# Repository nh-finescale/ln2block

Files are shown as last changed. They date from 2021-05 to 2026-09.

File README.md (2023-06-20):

# ln2block

ln2block is the combination of hardware and software to send block messages in a Fremo meeting between two block enabled stations. There are more implementations for this, which can be found at [fremo-block](http://fremo-block.sourceforge.net/) The ln2block variant aims to directly connect Loconet switchpanels to block. First implementation is done with https://smf-modelle.de/ Dr-S2 panels in the Loconet variant. But other implementations such as arduino based or felderblock are possible.

## hardware

The hardware is a adaption of the boards shown [here](http://fremo-block.sourceforge.net/Loconet2Block/index.html) with the following adaptations:
- Schlüesselinterface integrated
- Arduino Nano based to ease programming and debugging
- OLED status display

v5 is a variant which has connections on both ends of the pcb.
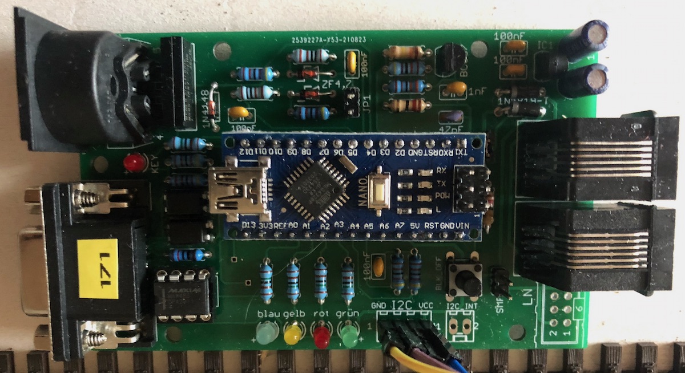
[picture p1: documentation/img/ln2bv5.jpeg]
v5 prototype


v6 is adapted to fit the Strapubox SP2000 (again).

## Getting parts:

Reichelt Shopping Cart for V5 parts: (https://www.reichelt.de/my/1871884). For logging purposes a SSD1306 OLED Display is used. Any I2C variant should work.

## Manuals:

See [the wiki](https://github.com/nh-finescale/ln2block/wiki)

## Software

Software is fully functional for:
* Tf71
* Relaisblock
* Felderblock

### Programming the Arduino

To program the Arduino please use the Arduino IDE.

#### Prerequisites:
* Wire Library (included within IDE): needed for the U8g2 Library
* U8g2 Library: to write text and/or graphic on the OLED display
* LocoNet Library: to send/receive Loconet messages

## Configuration

The ln2block software can be configured through LNCV programming. The values in scope are described at [fremo-block](http://fremo-block.sourceforge.net/Loconet2Block/config.html).
A spreadsheet to calculate the appropriate values for each LNCV is found at https://github.com/nh-finescale/ln2block/tree/main/documentation

This sheet also contains a HEX explanation to translate HEX values shown on the OLED display back into which LNCV are on and off.

## Module connectivity

todo

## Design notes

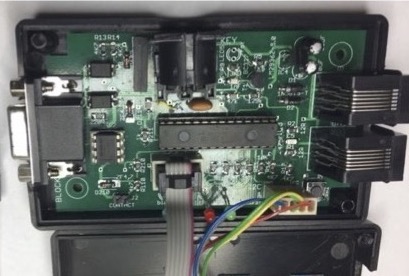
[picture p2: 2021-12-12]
documentation/img/400px/v4-400px.jpg

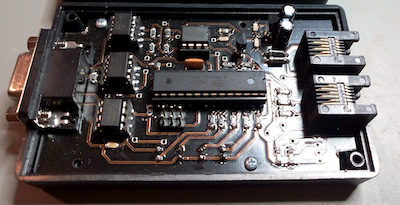
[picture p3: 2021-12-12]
documentation/img/400px/v2-400px.png

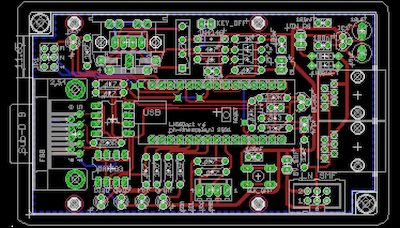
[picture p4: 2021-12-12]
documentation/img/400px/v6-400px.jpg

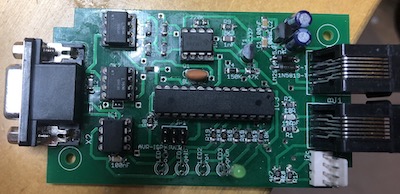
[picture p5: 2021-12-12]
documentation/img/400px/v3-400px.jpg

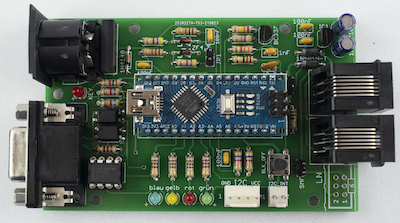
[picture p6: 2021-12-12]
documentation/img/400px/v5-400px.jpg

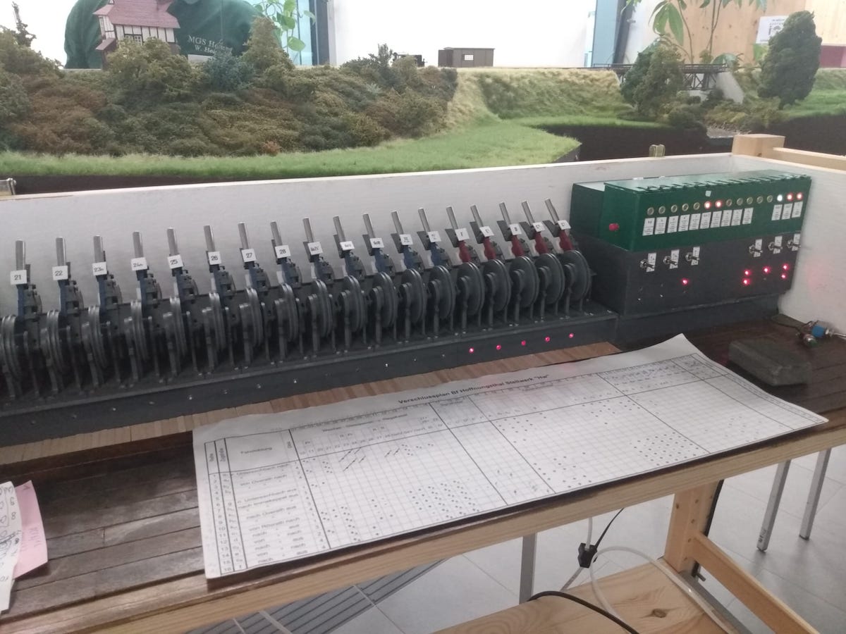
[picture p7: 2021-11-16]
documentation/img/Hoffnungstal.jpg

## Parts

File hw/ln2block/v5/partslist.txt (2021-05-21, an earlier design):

Partlist

Exported from ln2block_tht4.brd at 21/05/2021 09:19

EAGLE Version 7.6.0 Copyright (c) 1988-2016 CadSoft

Assembly variant: 

Part     Value                 Package           Library                Position (mm)         Orientation

C1       100nF                 C025-025X050      resistor               (83.5025 57.4675)     R180
C2       10uF                  E2,5-5            resistor               (95.25 55.245)        R90
C3       10uF                  E2,5-5            resistor               (95.25 61.595)        R270
C4       100nF                 C025-025X050      resistor               (83.5025 61.595)      R180
C5       100nF                 C025-025X050      resistor               (73.66 38.4175)       R90
C6       47pF                  C025-024X044      resistor               (74.6125 50.165)      R180
C7       1nF                   C025-025X050      resistor               (74.6125 53.975)      R0
C8       100nF                 C025-025X050      resistor               (56.515 59.055)       R90
C9       100nF                 C025-025X050      resistor               (35.8775 50.165)      R0
D1       1N5819-T              DO41-7.6          diode                  (86.0425 53.6575)     R0
D2                             DO41-7.6          diode                  (86.0425 50.4825)     R0
D3       1N4148                DO-1N4148         adafruit               (29.5275 54.61)       R270
D4       ZF4,7                 ZDIO-7.5          diode                  (48.5775 57.4675)     R0
D5       ZF4,7                 ZDIO-7.5          diode                  (48.5775 53.975)      R0
IC1      LM2936Z-5.0           TO92              national-semiconductor (90.17 58.42)         R270
IC2      MAX483                DIL08             maxim                  (25.4 15.5575)        R0
J1       RJ11-6L-B             RJ11-NO_SHIELD    con-tycoelectronics    (96.52 41.91)         R90
J2       I2C                   6410-04           con-molex              (73.66 10.795)        R180
J3       RJ11-6L-B             RJ11-NO_SHIELD    con-tycoelectronics    (96.52 25.4)          R90
J4       DIN                   6410-04           con-molex              (13.6525 52.07)       R270
JP1      J2                    JP1               jumper                 (56.515 52.3875)      R180
K1       Reichelt MS 7175-L 5V MEDER_MS_1A87-75L sbor                   (25.7175 60.96)       R270
LED1     gelb                  LED3MM            led                    (44.1325 10.16)       R90
LED2     rot                   LED3MM            led                    (49.8475 10.16)       R90
LED3     grün                  LED3MM            led                    (55.5625 10.16)       R90
LED4     rot                   LED3MM            led                    (61.595 10.16)        R90
LED5     blau                  LED3MM            led                    (38.735 10.16)        R90
M1       ARDUINO-NANO-3.0      ARDUINO-NANO-3.0  diy-modules            (55.88 37.1475)       R0
OK1      LTV816S               SMD4              optocoupler            (25.7175 29.21)       R270
OK2      LTV816S               SMD4              optocoupler            (25.7175 35.2425)     R270
R1       1K5                   0207/7            resistor               (44.1325 19.685)      R90
R2       1K5                   0207/7            resistor               (49.8475 19.685)      R90
R3       1K5                   0207/7            resistor               (55.5625 19.685)      R90
R4       4K7                   0207/7            resistor               (74.93 19.685)        R90
R5       4K7                   0207/7            resistor               (72.39 19.685)        R90
R6       1K5                   0207/7            resistor               (61.595 19.685)       R90
R7       12R                   0207/7            resistor               (83.82 33.655)        R90
R8       12R                   0207/7            resistor               (66.675 51.7525)      R180
R9       129k                  0207/7            resistor               (66.675 60.96)        R0
R10      3K3                   0207/7            resistor               (66.675 54.9275)      R0
R11      47k                   0207/7            resistor               (66.675 58.1025)      R180
R12      1K5                   0207/7            resistor               (39.0525 19.685)      R90
R13      220R                  0207/7            resistor               (25.0825 23.8125)     R0
R14      4K7                   0207/7            resistor               (26.035 40.005)       R0
R15      4K7                   0207/7            resistor               (26.035 42.8625)      R0
R16      4k7                   0207/7            resistor               (48.5775 50.8)        R0
R17      1k                    0207/7            resistor               (38.4175 53.975)      R0
R18      4k7                   0207/7            resistor               (38.4175 60.325)      R180
R19      1k                    0207/7            resistor               (48.5775 60.325)      R180
SW1      505-1-1-6-40-00       WS-TATV           fredi                  (87.63 12.7)          R270
T1       BC337                 TO92              transistor             (75.2475 59.3725)     R270
X1       Sub-D 9               F09HP             con-subd               (15.5575 24.4475)     R90
X2       DIN 5 180             MAB5SH            con-hirschmann         (13.335 52.07)        R270

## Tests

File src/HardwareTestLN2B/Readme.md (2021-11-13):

# HarwareTest

To test the ln2block hardware load the BlockPlatineTest software onto the Arduino Nano on the LN2B Board. In compile_options.h set the board version (supported as of now are 3,4,5 and 6).

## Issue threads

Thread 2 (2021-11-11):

Swap OLED Orientation

nh-finescale, 2021-11-11:
The OLED display is dependent on the orientation of board in the Stellwerk (if the OLED is mounted fixed on the board). To be able to read the OLED if mounted upside down, a configuration could be implemented this flips the OLED display upside down

Bahn-Papa, 2021-11-12:
Add a configuration bit 'DISPLAY_FLIP' that controls the orientation of the OLED display. If the bit is set the displayed text will be flipped (rotated by 180 degree).

Closed 2021-11-13.

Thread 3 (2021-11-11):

Handle Vorblock manually in Felderblock

nh-finescale, 2021-11-11:
A Vorblock should be handled manually in Felderblock, not automatically as in Tf71 and Relaisblock. Add a configuration switch to set Felderblock type and handle logic accordingly. Add Vorblock input Additionally?

nh-finescale, 2021-11-16:
need to test

nh-finescale, 2021-12-13:
No Vorblock possible is LNCV2 bit 4 set. Exit signal is not recognized, vorblock cannot be sent to other side

Bahn-Papa, 2022-01-05:
This bug is fixed and tested.
Felderblock is working as expected now.

Closed 2022-01-05.

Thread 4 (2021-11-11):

Reset 1ste Achse counter to simulate Letzte Achse

nh-finescale, 2021-11-11:
Reset timer for Letzte Achse after each Track Occupied message so that complete train is able to be detected before Rueckblock can be done

Closed 2021-11-15.

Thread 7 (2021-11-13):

block_on_off not working?

nh-finescale, 2021-11-13:
pressing block_on_of button does not result in clear shutdown of block

Bahn-Papa, 2022-01-05:
This feature is implemented now.
A short press to the button will toggle between Block ON and OFF.
The state will be shown on the display.

Closed 2022-01-05.

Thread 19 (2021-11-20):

Need to send EINFAHR_KONTAKT again to leave state 1._ACHSE

Kleinbahner, 2021-11-20:
When receiving a train, the message EINFAHR_KONTAKT has to be send in order to change the state to 1._ACHSE. Then a second message EINFAHR_KONTAKT has to be send in order to go to state GERAEUMT. This might be difficult when using a current sensor that is longer then the loco. There, only one message will be generated.
Could this be changed to automatically forward to the next state or to react on a inverted EINFAHR_KONTAKT message (contact released)?

nh-finescale, 2021-11-30:
issue is related to new config bits for 3 timers, which is separate issue. This one can be closed

Closed 2021-11-30.

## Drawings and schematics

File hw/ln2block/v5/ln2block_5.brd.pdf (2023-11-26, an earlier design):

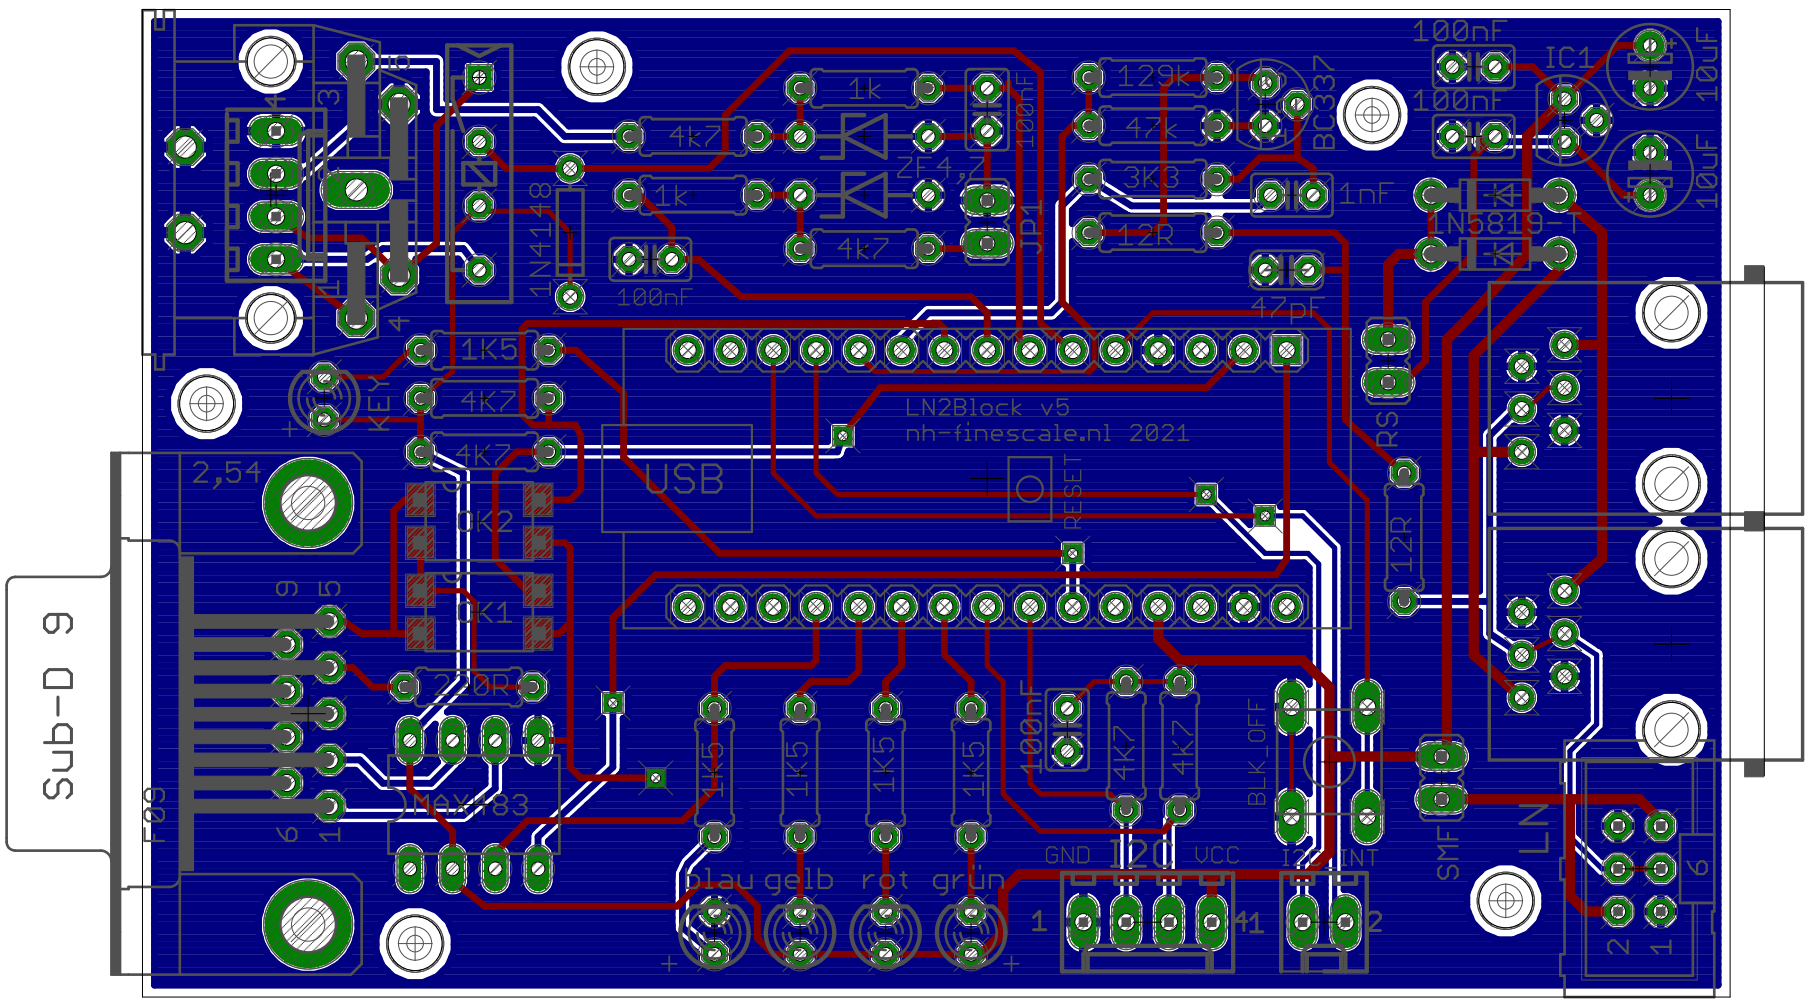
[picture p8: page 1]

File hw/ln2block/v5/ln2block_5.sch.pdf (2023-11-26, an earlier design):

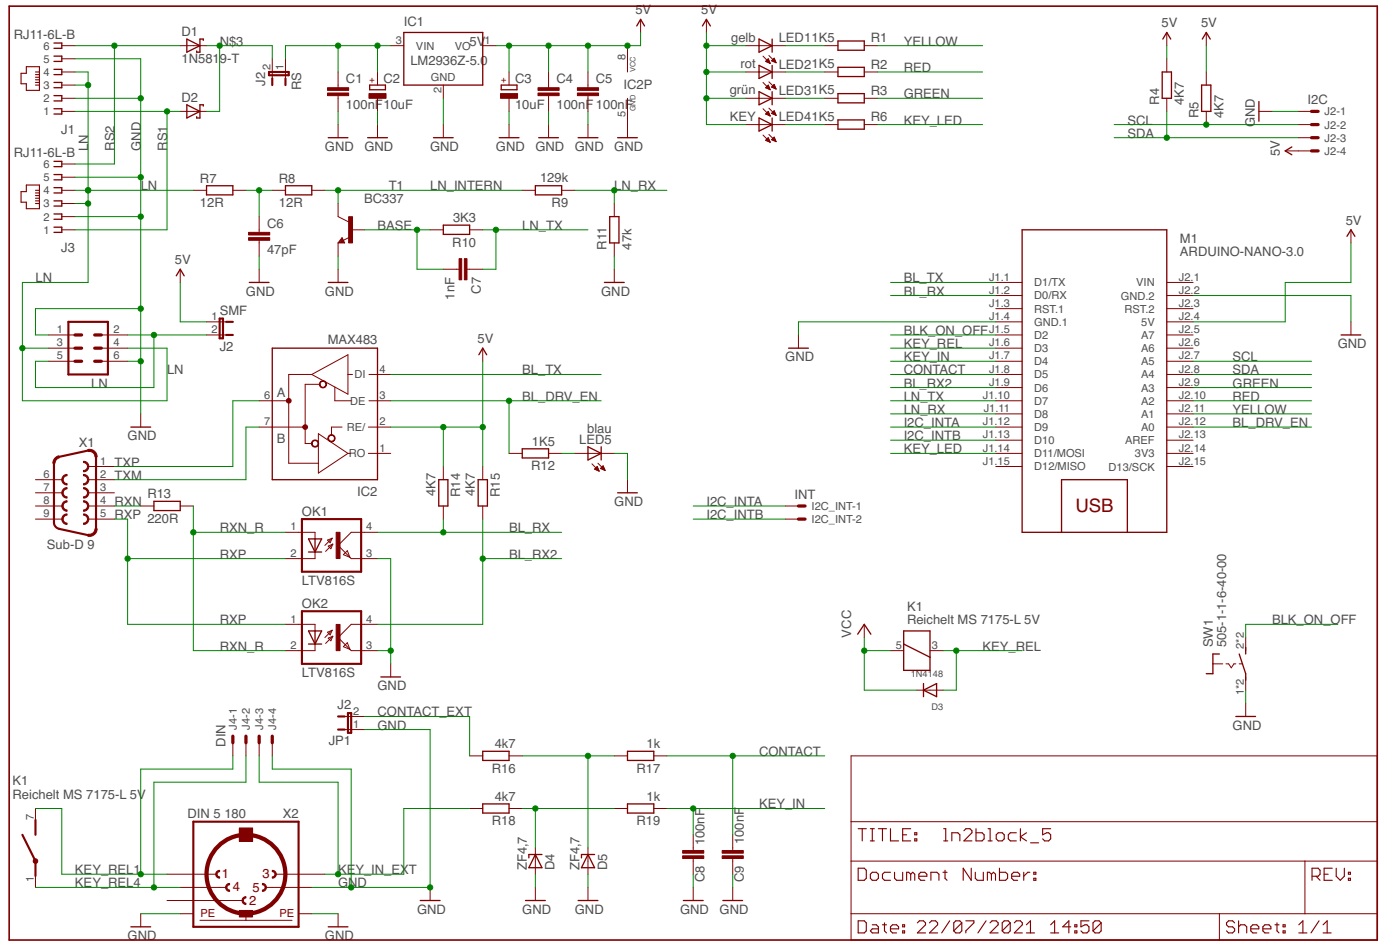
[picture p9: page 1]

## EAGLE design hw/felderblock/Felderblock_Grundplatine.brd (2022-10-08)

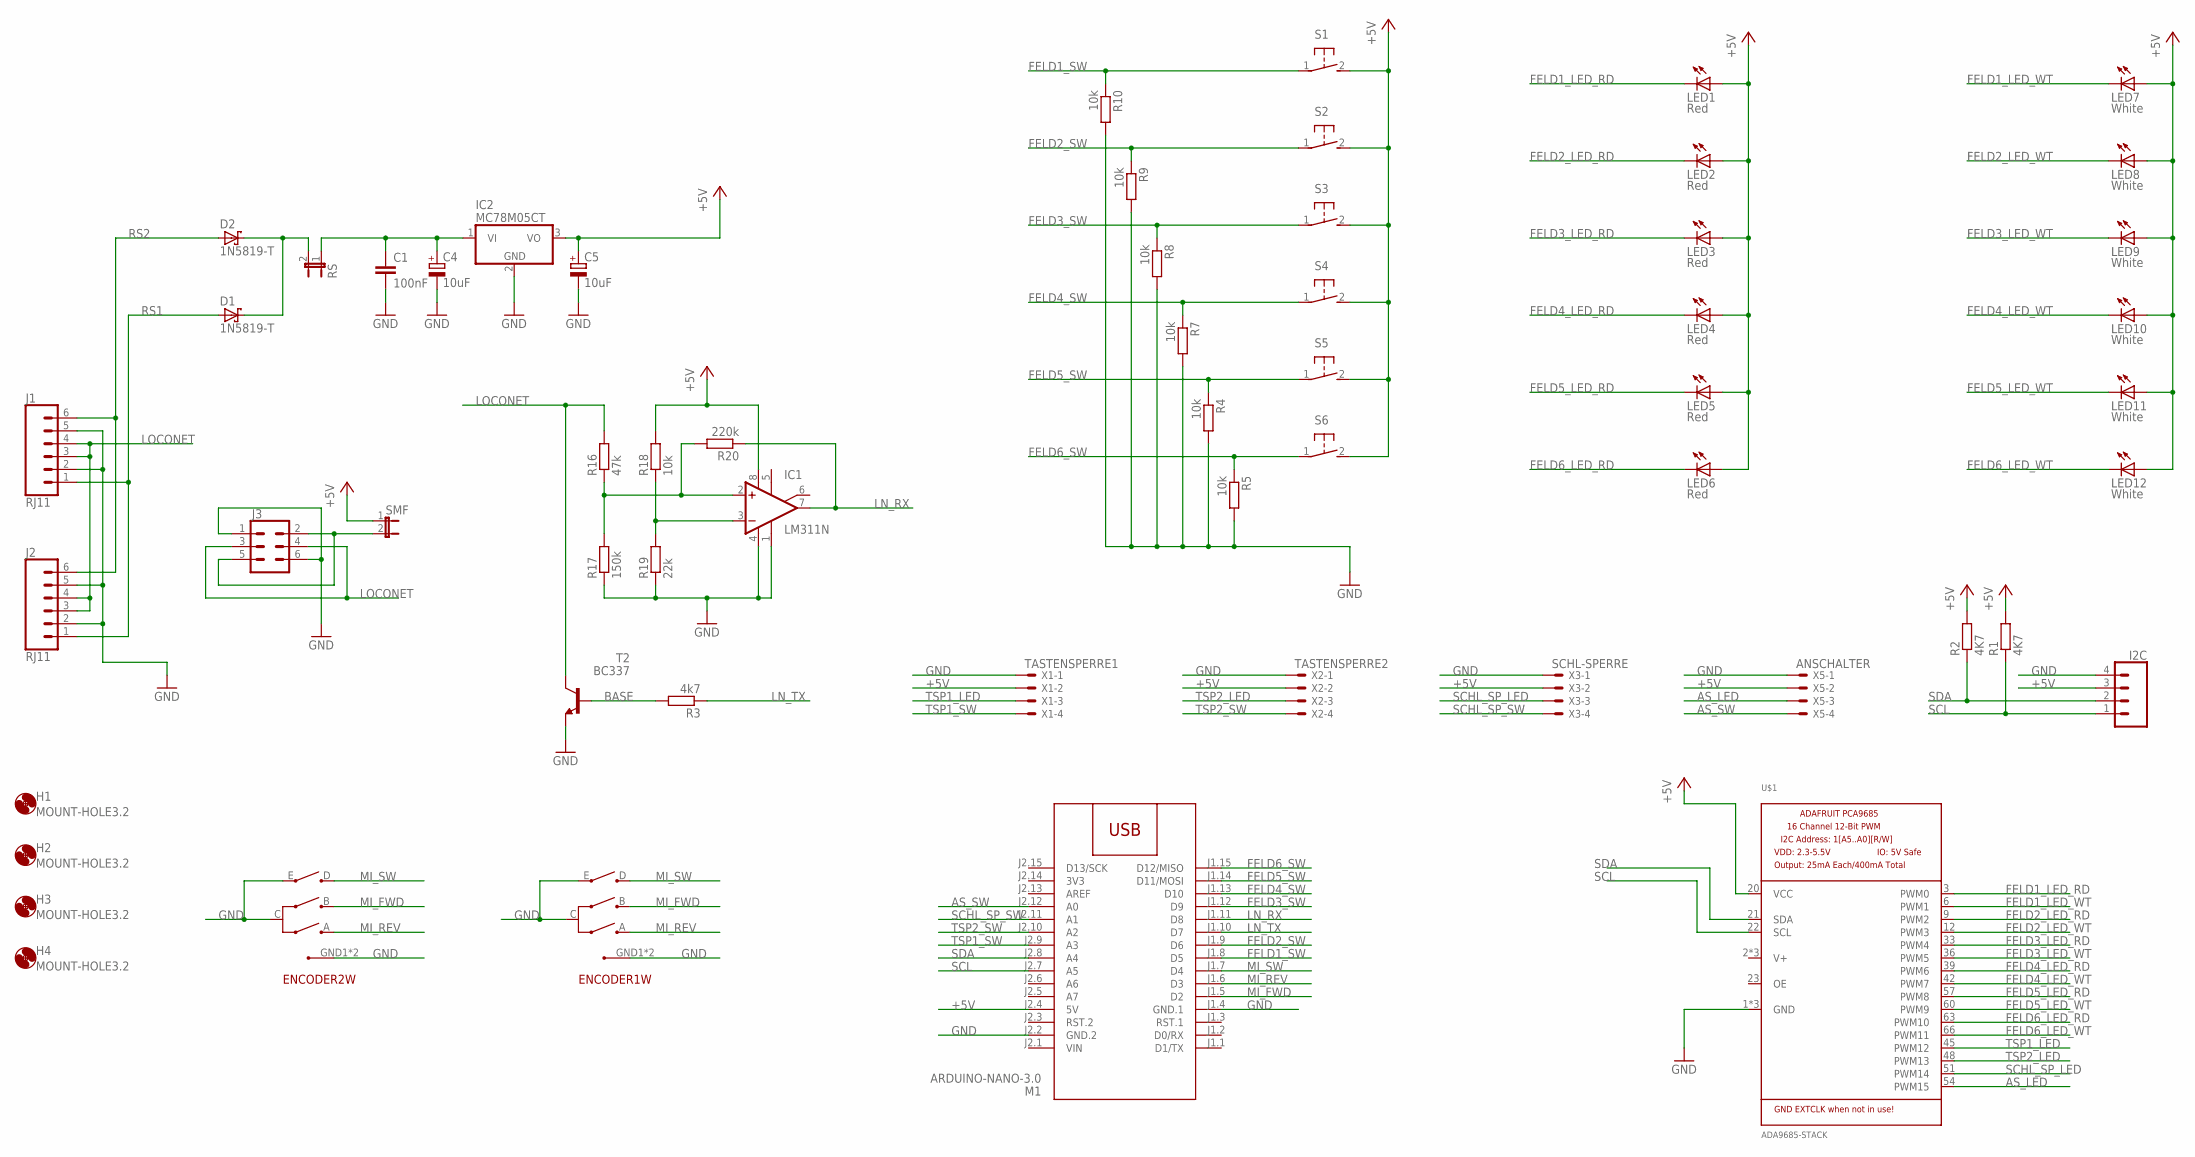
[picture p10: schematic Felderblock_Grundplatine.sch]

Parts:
C1: 100nF; C025-025X050
C4, C5: 10uF; E2-5
D1, D2: 1N5819-T; DO41-7.6
ENCODER1, ENCODER2: EC11B42AE; EC11B42
H1, H2, H3, H4: MOUNT-HOLE3.2; 3,2
I2C: CONN_04JST-PTH-VERT; JST-4-PTH-VERT
IC1: LM311N; DIL08
IC2: MC78M05CT; TO220V
J1, J2: RJ11; RJ11-6
J3: CONN_03X2SHROUD; 2X3-SHROUDED
LED1, LED2, LED3, LED4, LED5, LED6: Red; LED3MM
LED7, LED8, LED9, LED10, LED11, LED12: White; LED3MM
M1: ARDUINO-NANO-3.0
R1, R2: 4K7; 0207/7
R3: 4k7; 0207/7
R4, R5, R7, R8, R9, R10, R18: 10k; 0207/7
R16: 47k; 0207/7
R17: 150k; 0207/7
R19: 22k; 0207/7
R20: 220k; 0207/7
RS: JP1E; JP1
S1, S2, S3, S4, S5, S6: 31-XX; B3F-31XX
SMF: JP1E; JP1
T2: BC337; TO92
U$1: ADA9685-STACK
X1: TASTENSPERRE1; 22-23-2041
X2: TASTENSPERRE2; 22-23-2041
X3: SCHL-SPERRE; 22-23-2041
X5: ANSCHALTER; 22-23-2041

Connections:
3V3: M1.J2.14 (3V3)
+5V: C5.+, I2C.3, IC1.8 (V+), IC2.3 (VO), LED1.A, LED2.A, LED3.A, LED4.A, LED5.A, LED6.A, LED7.A, LED8.A, LED9.A, LED10.A, LED11.A, LED12.A, M1.J2.4 (5V), R1.2, R2.2, R18.2, S1.2 (S), S2.2 (S), S3.2 (S), S4.2 (S), S5.2 (S), S6.2 (S), SMF.1, U$1.20 (VCC), X1.2, X2.2, X3.2, X5.2
AS_LED: U$1.54 (PWM15), X5.3
AS_SW: M1.J2.12 (A0), X5.4
BASE: R3.2, T2.2 (B)
FELD1_LED_RD: LED1.K (C), U$1.3 (PWM0)
FELD1_LED_WT: LED7.K (C), U$1.6 (PWM1)
FELD1_SW: M1.J1.8 (D5), R10.1, S1.1
FELD2_LED_RD: LED2.K (C), U$1.9 (PWM2)
FELD2_LED_WT: LED8.K (C), U$1.12 (PWM3)
FELD2_SW: M1.J1.9 (D6), R9.1, S2.1
FELD3_LED_RD: LED3.K (C), U$1.33 (PWM4)
FELD3_LED_WT: LED9.K (C), U$1.36 (PWM5)
FELD3_SW: M1.J1.12 (D9), R8.1, S3.1
FELD4_LED_RD: LED4.K (C), U$1.39 (PWM6)
FELD4_LED_WT: LED10.K (C), U$1.42 (PWM7)
FELD4_SW: M1.J1.13 (D10), R7.1, S4.1
FELD5_LED_RD: LED5.K (C), U$1.57 (PWM8)
FELD5_LED_WT: LED11.K (C), U$1.60 (PWM9)
FELD5_SW: M1.J1.14 (D11/MOSI), R4.1, S5.1
FELD6_LED_RD: LED6.K (C), U$1.63 (PWM10)
FELD6_LED_WT: LED12.K (C), U$1.66 (PWM11)
FELD6_SW: M1.J1.15 (D12/MISO), R5.1, S6.1
GND: C1.2, C4.-, C5.-, ENCODER1.C, ENCODER1.E, ENCODER1.GND1 (GND), ENCODER1.GND2 (GND), ENCODER2.C, ENCODER2.E, ENCODER2.GND1 (GND), ENCODER2.GND2 (GND), I2C.4, IC1.1 (GND), IC1.4 (V-), IC2.2 (GND), J1.2, J1.5, J2.2, J2.5, J3.1, J3.6, M1.J1.4 (GND.1), M1.J2.2 (GND.2), R4.2, R5.2, R7.2, R8.2, R9.2, R10.2, R17.1, R19.1, T2.1 (E), U$1.1 (GND), U$1.24 (GND), U$1.52 (GND), X1.1, X2.1, X3.1, X5.1
LN_RX: IC1.7 (OUT), M1.J1.11 (D8), R20.1
LN_TX: M1.J1.10 (D7), R3.1
LOCONET: J1.3, J1.4, J2.3, J2.4, J3.3, J3.4, R16.2, T2.3 (C)
MI_FWD: ENCODER1.B, ENCODER2.B, M1.J1.5 (D2)
MI_REV: ENCODER1.A, ENCODER2.A, M1.J1.6 (D3)
MI_SW: ENCODER1.D, ENCODER2.D, M1.J1.7 (D4)
unnamed: IC1.2 (+IN), R16.1, R17.2, R20.2
unnamed: D1.C, D2.C, RS.2
unnamed: C1.1, C4.+, IC2.1 (VI), RS.1
unnamed: IC1.3 (-IN), R18.1, R19.2
unnamed: J3.2, J3.5, SMF.2
RS1: D1.A, J1.1, J2.1
RS2: D2.A, J1.6, J2.6
SCHL_SP_LED: U$1.51 (PWM14), X3.3
SCHL_SP_SW: M1.J2.11 (A1), X3.4
SCL: I2C.1, M1.J2.7 (A5), R1.1, U$1.22 (SCL)
SDA: I2C.2, M1.J2.8 (A4), R2.1, U$1.21 (SDA)
TSP1_LED: U$1.45 (PWM12), X1.3
TSP1_SW: M1.J2.9 (A3), X1.4
TSP2_LED: U$1.48 (PWM13), X2.3
TSP2_SW: M1.J2.10 (A2), X2.4
VIN: M1.J2.1 (VIN)

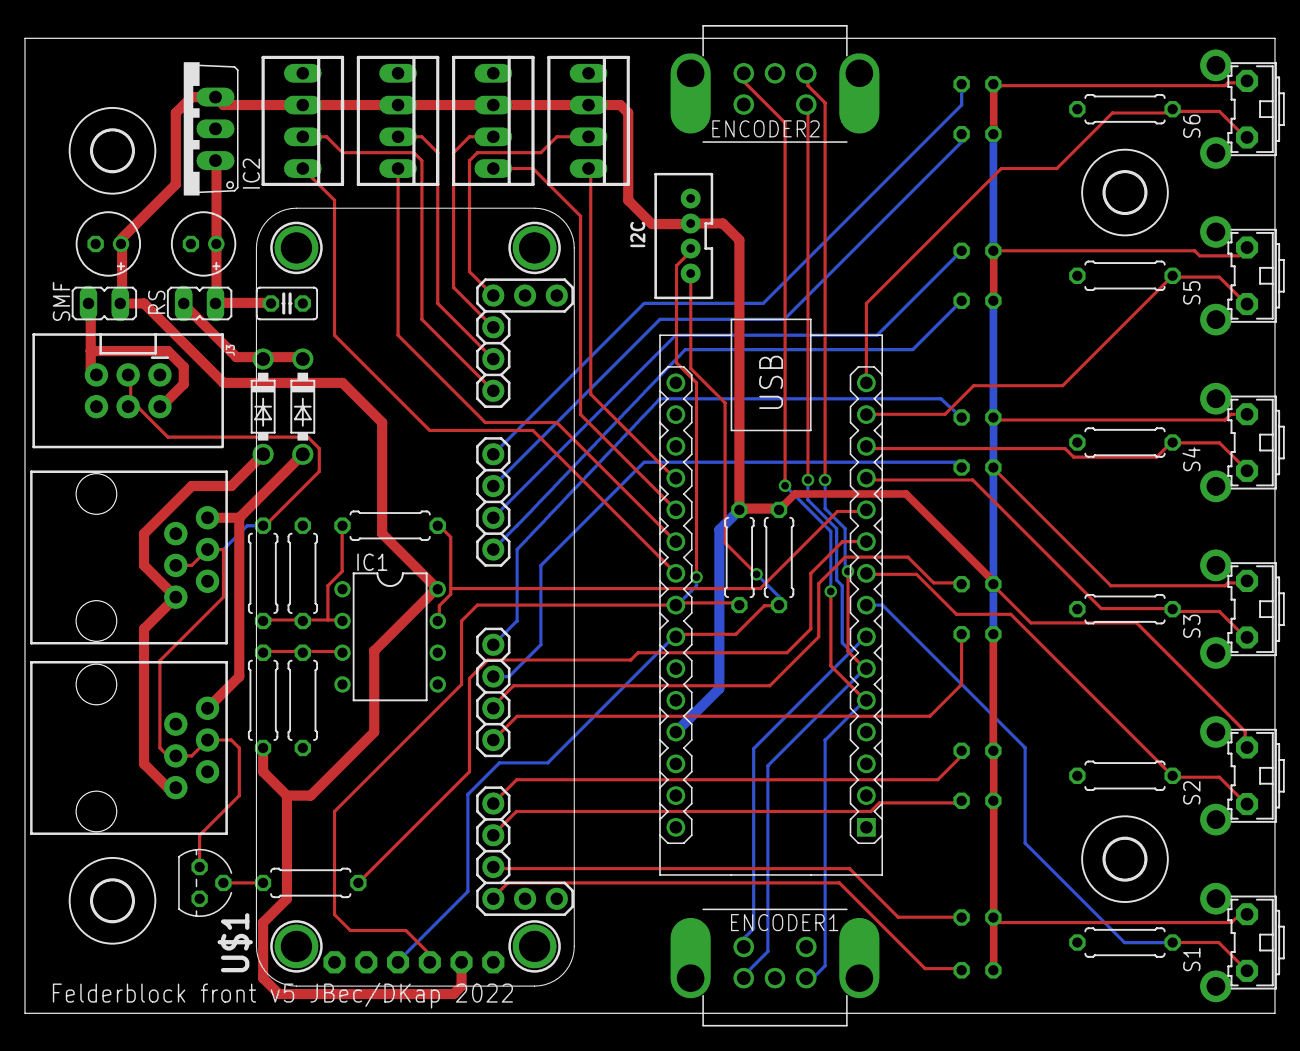
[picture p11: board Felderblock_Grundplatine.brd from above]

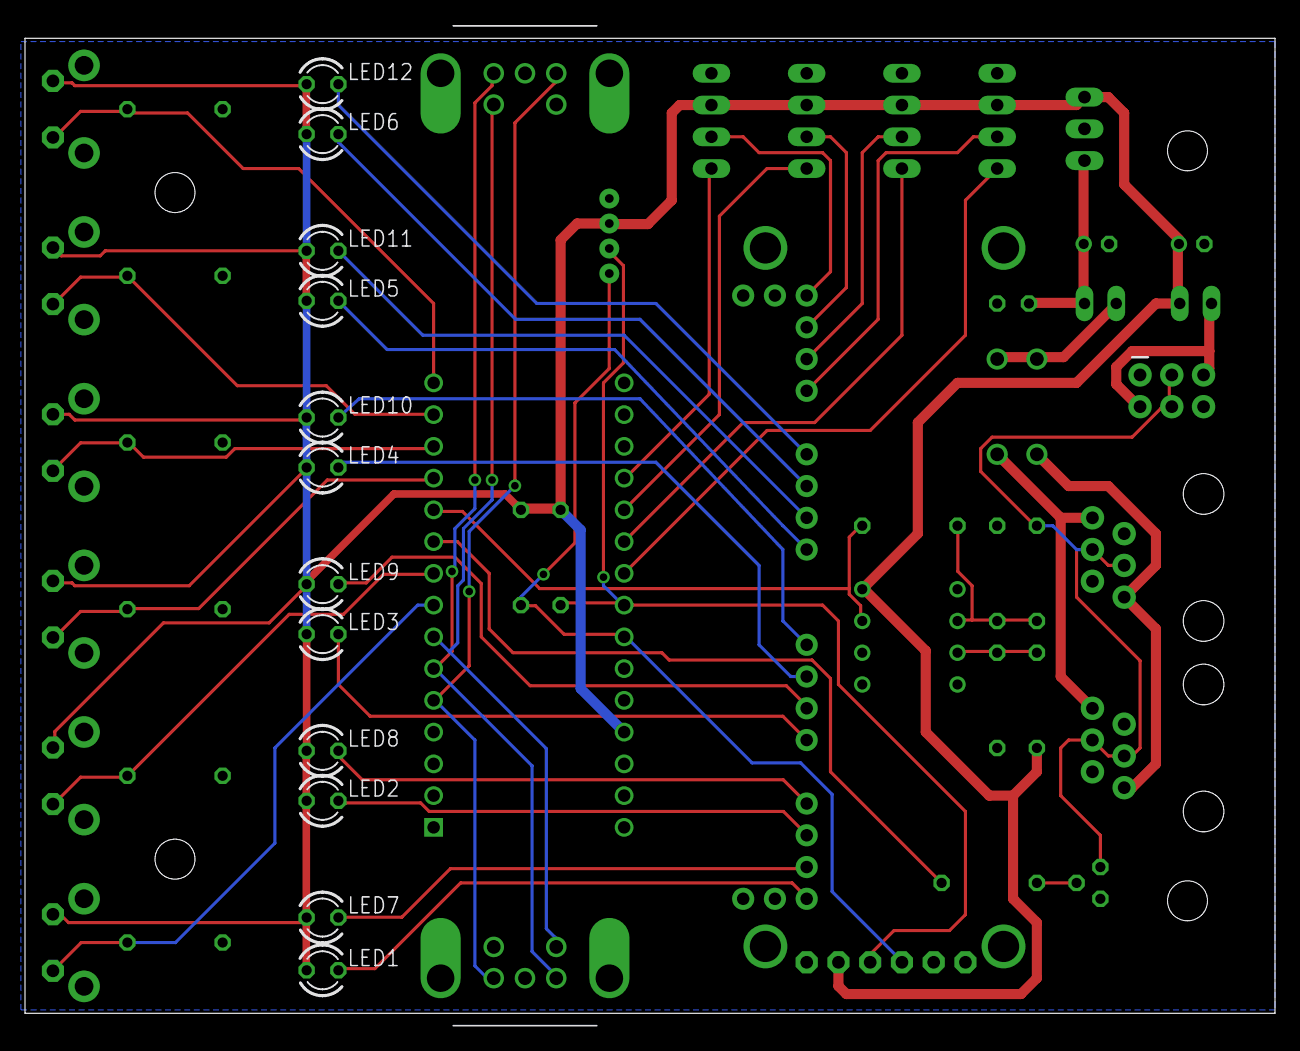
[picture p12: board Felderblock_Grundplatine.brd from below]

Board: 2 copper layers, 100.0 x 80.0 mm, 58 parts (12 on the bottom side), 44 nets.

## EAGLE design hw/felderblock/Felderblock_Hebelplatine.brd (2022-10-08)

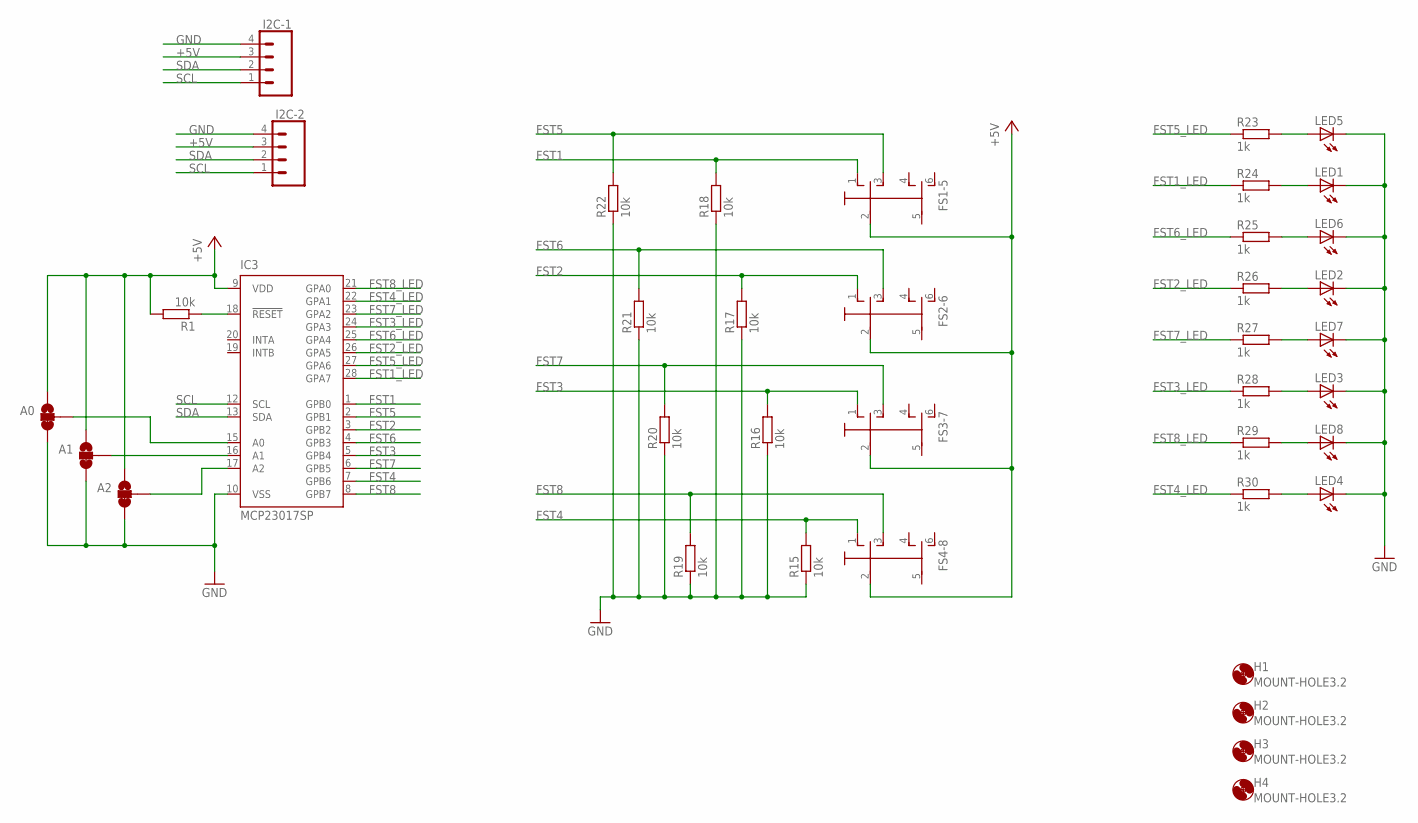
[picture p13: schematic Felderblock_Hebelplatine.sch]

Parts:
A0, A1, A2: JUMPER-SMT_3_1-NC_TRACE_SILK; SMT-JUMPER_3_1-NC_TRACE_SILK
FS1-5, FS2-6, FS3-7, FS4-8: SW_2POL_ON-OFF-ONSOLDERPAD; DIL6_LARGE
H1, H2, H3, H4: MOUNT-HOLE3.2; 3,2
I2C-1, I2C-2: CONN_04JST-PTH-VERT; JST-4-PTH-VERT
IC3: MCP23017SP; DIL28-3
LED1, LED2, LED3, LED4, LED5, LED6, LED7, LED8: LED3MM
R1, R15, R16, R17, R18, R19, R20, R21, R22: 10k; 0207/7
R23, R24, R25, R26, R27, R28, R29, R30: 1k; 0207/7

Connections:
+5V: A0.1, A1.1, A2.1, FS1-5.2, FS2-6.2, FS3-7.2, FS4-8.2, I2C-1.3, I2C-2.3, IC3.9 (VDD), R1.2
FST1: FS1-5.1 (O), IC3.1 (GPB0), R18.2
FST1_LED: IC3.28 (GPA7), R24.1
FST2: FS2-6.1 (O), IC3.3 (GPB2), R17.2
FST2_LED: IC3.26 (GPA5), R26.1
FST3: FS3-7.1 (O), IC3.5 (GPB4), R16.2
FST3_LED: IC3.24 (GPA3), R28.1
FST4: FS4-8.1 (O), IC3.7 (GPB6), R15.2
FST4_LED: IC3.22 (GPA1), R30.1
FST5: FS1-5.3 (S), IC3.2 (GPB1), R22.2
FST5_LED: IC3.27 (GPA6), R23.1
FST6: FS2-6.3 (S), IC3.4 (GPB3), R21.2
FST6_LED: IC3.25 (GPA4), R25.1
FST7: FS3-7.3 (S), IC3.6 (GPB5), R20.2
FST7_LED: IC3.23 (GPA2), R27.1
FST8: FS4-8.3 (S), IC3.8 (GPB7), R19.2
FST8_LED: IC3.21 (GPA0), R29.1
GND: A0.3, A1.3, A2.3, I2C-1.4, I2C-2.4, IC3.10 (VSS), LED1.K (C), LED2.K (C), LED3.K (C), LED4.K (C), LED5.K (C), LED6.K (C), LED7.K (C), LED8.K (C), R15.1, R16.1, R17.1, R18.1, R19.1, R20.1, R21.1, R22.1
unnamed: A0.2, IC3.15 (A0)
unnamed: A2.2, IC3.17 (A2)
unnamed: A1.2, IC3.16 (A1)
unnamed: IC3.18 (!RESET), R1.1
unnamed: LED5.A, R23.2
unnamed: LED1.A, R24.2
unnamed: LED6.A, R25.2
unnamed: LED2.A, R26.2
unnamed: LED7.A, R27.2
unnamed: LED3.A, R28.2
unnamed: LED8.A, R29.2
unnamed: LED4.A, R30.2
SCL: I2C-1.1, I2C-2.1, IC3.12 (SCL)
SDA: I2C-1.2, I2C-2.2, IC3.13 (SDA)

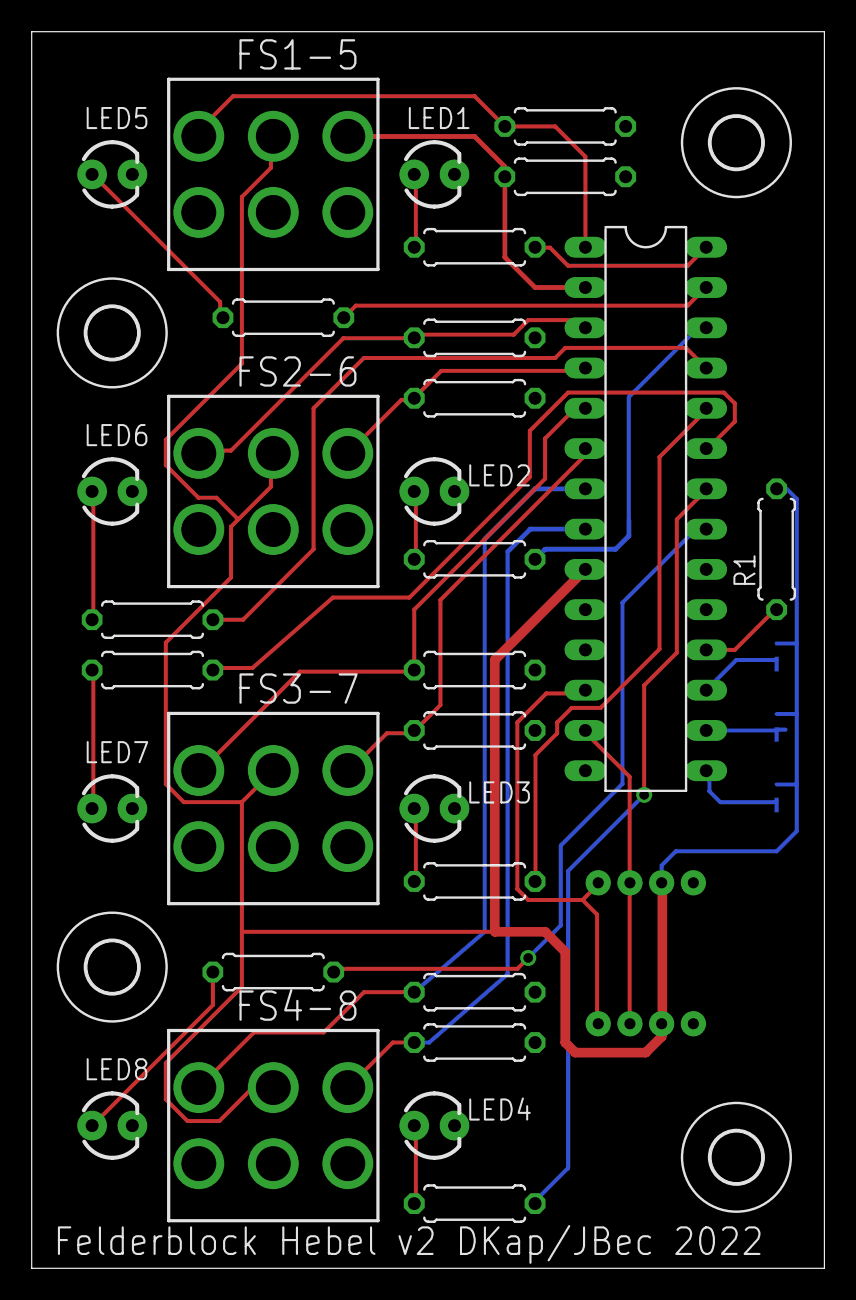
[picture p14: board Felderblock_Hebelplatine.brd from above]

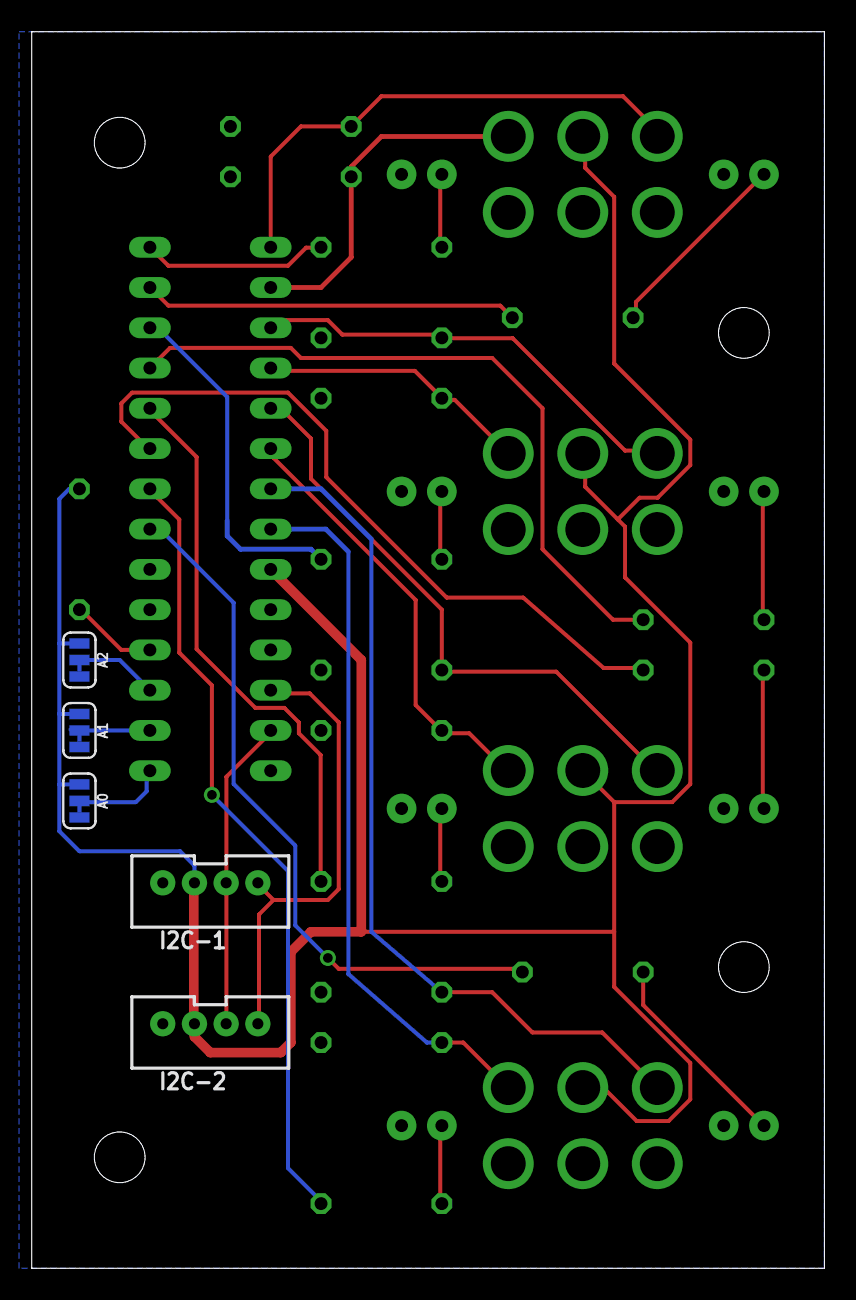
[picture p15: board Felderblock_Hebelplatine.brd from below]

Board: 2 copper layers, 50.0 x 78.0 mm, 39 parts (5 on the bottom side), 32 nets.

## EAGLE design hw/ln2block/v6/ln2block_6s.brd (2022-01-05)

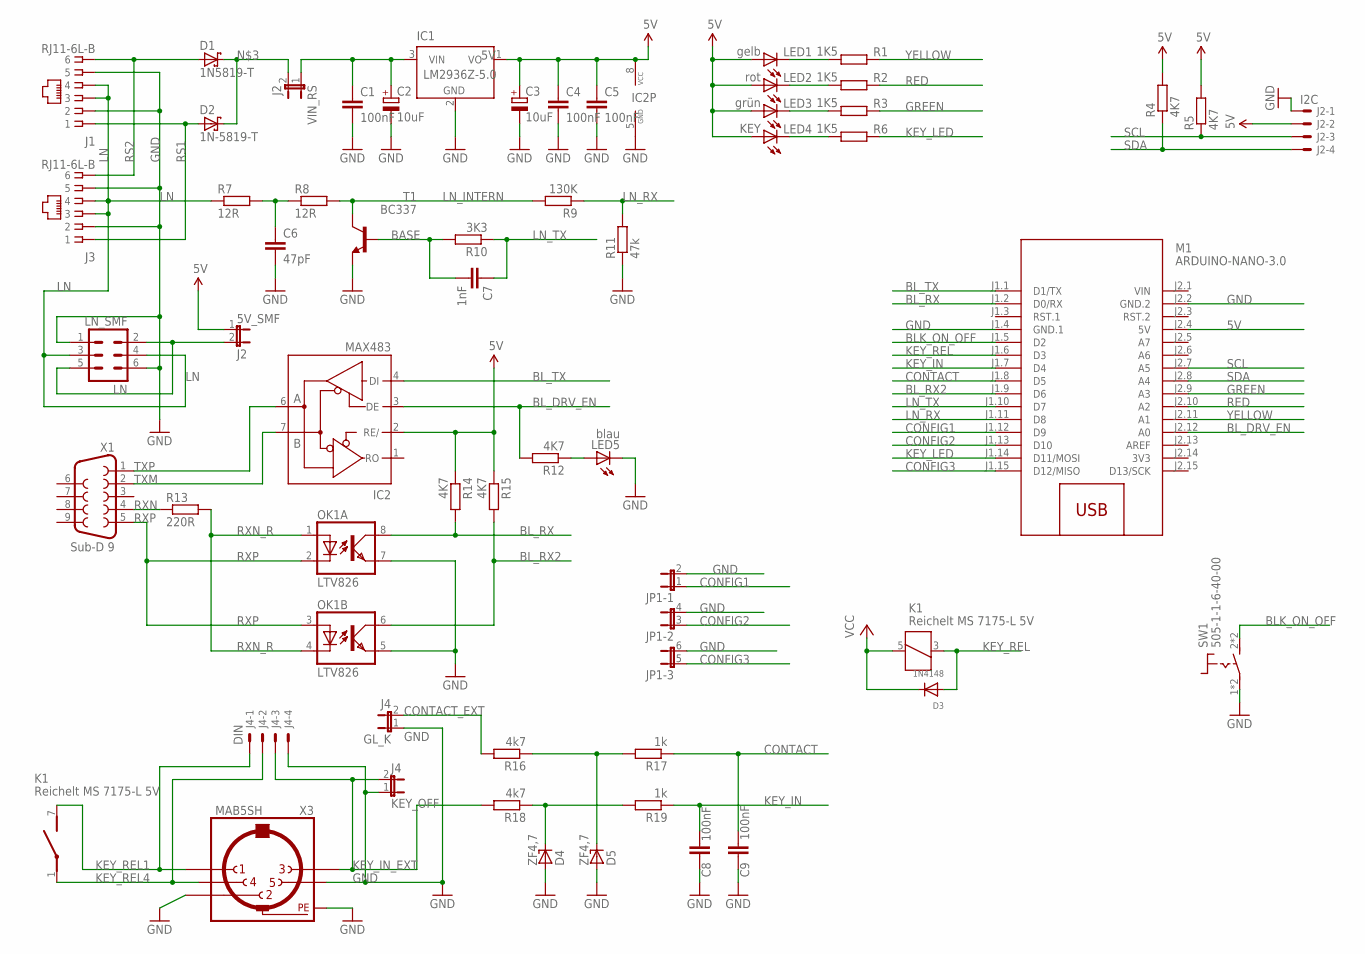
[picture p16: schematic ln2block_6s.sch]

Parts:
5V_SMF: J2; JP1
C1, C4, C5, C8, C9: 100nF; C025-025X050
C2, C3: 10uF; E2,5-5
C6: 47pF; C025-024X044
C7: 1nF; C025-025X050
D1: 1N5819-T; DO41-7.6
D2: 1N-5819-T; DO41-7.6
D3: 1N4148; DO-1N4148
D4, D5: ZF4,7; ZDIO-7.5
GL_K: J4; JP1
IC1: LM2936Z-5.0; TO92
IC2: MAX483; DIL08
J1, J3: RJ11-6L-B; RJ11-NO_SHIELD
J2: I2C; 6410-04
J4: DIN; 6410-04
JP1: JP3QE; JP3Q
K1: Reichelt MS 7175-L 5V; MEDER_MS_1A87-75L
KEY_OFF: J4; JP1
LED1: gelb; LED3MM
LED2: rot; LED3MM
LED3: grün; LED3MM
LED4: KEY; LED3MM
LED5: blau; LED3MM
LN: LN_SMF; CON-HARTING-ML_ML6
M1: ARDUINO-NANO-3.0
OK1: LTV826; DIL08
R1, R2, R3, R6: 1K5; 0207/7
R4, R5, R12, R14, R15: 4K7; 0207/7
R7, R8: 12R; 0207/7
R9: 130K; 0207/7
R10: 3K3; 0207/7
R11: 47k; 0207/7
R13: 220R; 0207/7
R16, R18: 4k7; 0207/7
R17, R19: 1k; 0207/7
SW1: 505-1-1-6-40-00; WS-TATV
T1: BC337; TO92
VIN_RS: J2; JP1
X1: Sub-D 9; F09HP
X3: MAB5SH

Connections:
3V3: M1.J2.14 (3V3)
5V: 5V_SMF.1, C3.+, C4.1, C5.1, D3.C, IC1.1 (VO), IC2.2 (RE/), IC2.8 (VCC), J2.2, K1.5, LED1.A, LED2.A, LED3.A, LED4.A, M1.J2.4 (5V), R4.2, R5.2, R14.1, R15.1
BASE: C7.2, R10.2, T1.2 (B)
BLK_ON_OFF: M1.J1.5 (D2), SW1.2 (S), SW1.4 (S)
BL_DRV_EN: IC2.3 (DE), M1.J2.12 (A0), R12.2
BL_RX: M1.J1.2 (D0/RX), OK1.8 (COL), R14.2
BL_RX2: M1.J1.9 (D6), OK1.6 (COL), R15.2
BL_TX: IC2.4 (DI), M1.J1.1 (D1/TX)
CONFIG1: JP1.1, M1.J1.12 (D9)
CONFIG2: JP1.3 (1), M1.J1.13 (D10)
CONFIG3: JP1.5 (1), M1.J1.15 (D12/MISO)
CONTACT: C9.2, M1.J1.8 (D5), R17.1
CONTACT_EXT: GL_K.2, R16.2
GND: C1.2, C2.-, C3.-, C4.2, C5.2, C6.2, C8.1, C9.1, D4.A, D5.A, GL_K.1, IC1.2 (GND), IC2.5 (GND), J1.2, J1.5, J2.1, J3.2, J3.5, J4.4, JP1.2, JP1.4 (2), JP1.6 (2), KEY_OFF.1, LED5.K (C), LN.1, LN.6, M1.J1.4 (GND.1), M1.J2.2 (GND.2), OK1.5 (EMIT), OK1.7 (EMIT), R11.1, SW1.1, SW1.3, T1.1 (E), X3.5, X3.PE, X3.PE1 (PE), X3.PE2 (PE), X3.PE@ (PE)
GREEN: M1.J2.9 (A3), R3.2
KEY_IN: C8.2, M1.J1.7 (D4), R19.1
KEY_IN_EXT: J4.3, KEY_OFF.2, R18.2, X3.3
KEY_LED: M1.J1.14 (D11/MOSI), R6.2
KEY_REL: D3.A, K1.3, M1.J1.6 (D3)
KEY_REL1: J4.1, K1.7 (S), X3.1
KEY_REL4: J4.2, K1.1, X3.4
LN: J1.3, J1.4, J3.3, J3.4, LN.3, LN.4, R7.1
LN_INTERN: R8.2, R9.2, T1.3 (C)
LN_PLUS: C1.1, C2.+, IC1.3 (VIN), VIN_RS.1
LN_RX: M1.J1.11 (D8), R9.1, R11.2
LN_TX: C7.1, M1.J1.10 (D7), R10.1
unnamed: LED4.K (C), R6.1
unnamed: LED5.A, R12.1
unnamed: D1.C, D2.C, VIN_RS.2
unnamed: 5V_SMF.2, LN.2, LN.5
unnamed: D4.C, R18.1, R19.2
unnamed: C6.1, R7.2, R8.1
unnamed: D5.C, R16.1, R17.2
unnamed: LED1.K (C), R1.1
unnamed: LED2.K (C), R2.1
unnamed: LED3.K (C), R3.1
RED: M1.J2.10 (A2), R2.2
RS1: D2.A, J1.1, J3.1
RS2: D1.A, J1.6, J3.6
RXN: R13.1, X1.4
RXN_R: OK1.1 (A), OK1.4 (C), R13.2
RXP: OK1.2 (C), OK1.3 (A), X1.5
SCL: J2.3, M1.J2.7 (A5), R5.1
SDA: J2.4, M1.J2.8 (A4), R4.1
TXM: IC2.7 (B), X1.2
TXP: IC2.6 (A), X1.1
VIN: M1.J2.1 (VIN)
YELLOW: M1.J2.11 (A1), R1.2

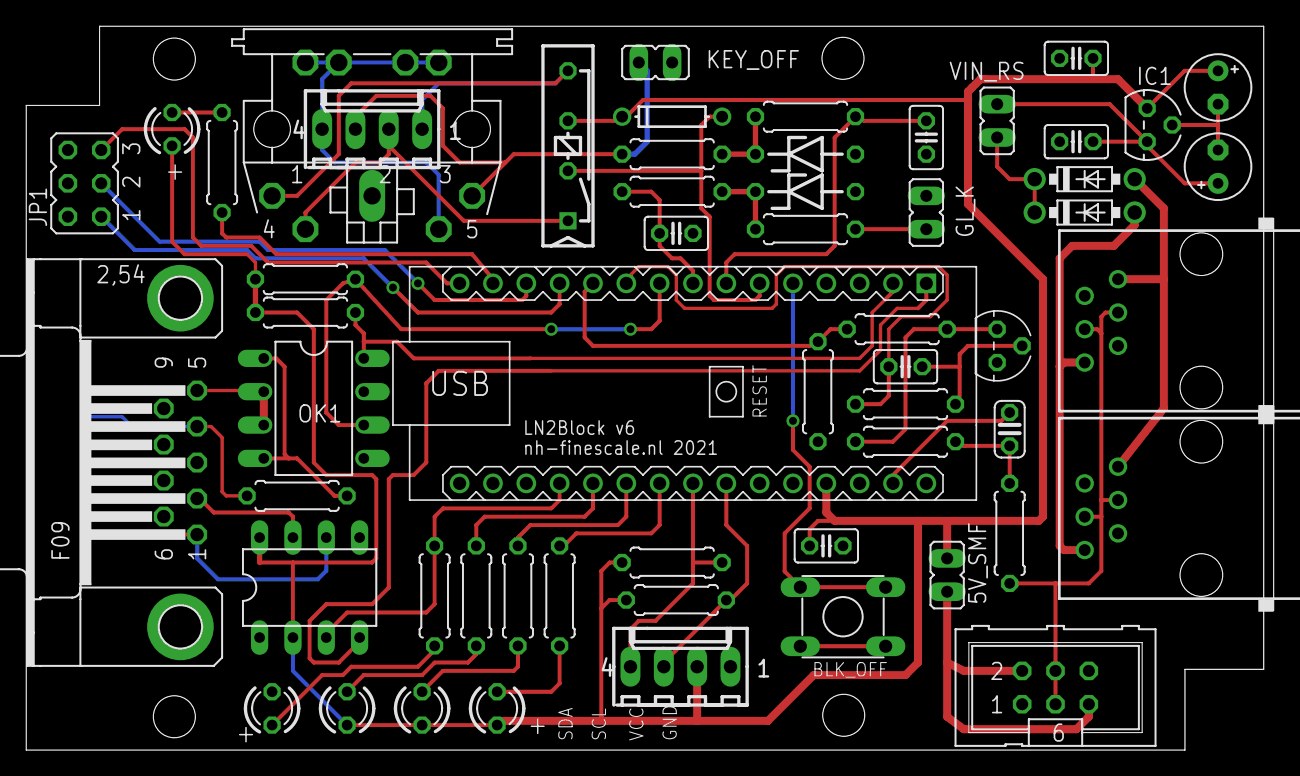
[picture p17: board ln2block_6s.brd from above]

Board: 2 copper layers, 95.0 x 55.1 mm, 57 parts (0 on the bottom side), 46 nets.

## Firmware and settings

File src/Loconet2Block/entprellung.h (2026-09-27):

#pragma once

//##########################################################################
//#
//#		EntprellungClass
//#
//#	Diese Klasse hilft bei der Entprellung von Tasten oder Ähnliches,
//#	die an einem Port angeschlossen sind.
//#
//#-------------------------------------------------------------------------
//#
//#	File Version:	2		from: 17.10.2025
//#
//#	Implementation:
//#		-	add low active and repeat functions
//#
//#-------------------------------------------------------------------------
//#
//#	File Version:	1		from: 10.08.2021
//#
//#	Implementation:
//#		-	first working version
//#			based on an algorithem from Peter Dannegger
//#
//##########################################################################


//==========================================================================
//
//		I N C L U D E S
//
//==========================================================================

#include <stdint.h>


//==========================================================================
//
//		D E F I N I T I O N S
//
//==========================================================================

#define	DEFAULT_REPEAT_START	100
#define DEFAULT_REPEAT_NEXT		 20


//==========================================================================
//
//		C L A S S   D E F I N I T I O N S
//
//==========================================================================


///////////////////////////////////////////////////////////////////////
//	CLASS:	EntprellungClass
//
//	Diese Klasse enthält Funktionen zum Entprellen von Eingängen.
//
class EntprellungClass
{
	private:
		//--------------------------------------------------------------
		//		m_usRepeatMask
		//	enthält die Maske, welche Tasten mit der Repeat-Funktion
		//	genutzt werden können.
		//
		uint8_t	m_usRepeatMask;

		//--------------------------------------------------------------
		//		m_usRepeatStart
		//
		//	contains the delay counts before the repeat function starts
		//
		uint8_t m_usRepeatStart;

		//--------------------------------------------------------------
		//		m_usRepeatNext
		//
		//	contains the delay count between two repeat steps
		//
		uint8_t m_usRepeatNext;

		//--------------------------------------------------------------
		//		m_usLowActiveMask
		//
		//	contains the low active bit mask
		//
		uint8_t m_usLowActiveMask;

		//--------------------------------------------------------------
		//		m_uiKeyState
		//	enthält den entprellten Tastenzustand (1 = Taste gedrückt)
		//
		uint8_t m_uiKeyState;

		//--------------------------------------------------------------
		//		m_uiKeyPress
		//	enthält die Info, welche Taste kurz gedrückt wurde.
		//
		uint8_t m_uiKeyPress;

		//--------------------------------------------------------------
		//		m_uiKeyRepeat
		//	enthält die Info, welche Taste lange gedrückt wurde.
		//
		uint8_t m_uiKeyRepeat;

		//--------------------------------------------------------------
		//		m_uiEntprellung1
		//		m_uiEntprellung2
		//		m_uiRepeatCounter
		//	Hilfsvariable um die Tastenentprellung durchführen
		//	zu können.
		//
		uint8_t m_uiEntprellung1;
		uint8_t m_uiEntprellung2;
		uint8_t m_uiRepeatCounter;

	public:
		EntprellungClass( uint8_t repeatMask );
		EntprellungClass( uint8_t repeatMask, uint8_t low_active );
		EntprellungClass( uint8_t repeatMask, uint8_t repeatStart, uint8_t repeatNext );

		//--------------------------------------------------------------
		//	Hier findet die eigentliche Entprellung statt.
		//	Diese Funktion muss daher möglichst schnell und oft
		//	aufgerufen werden.
		//	Als Parameter erhält die Funktion den PIN-Wert des Ports,
		//	der entprellt werden soll.
		//
		void Work( uint8_t keyIn );


		//--------------------------------------------------------------
		//	Gibt die Information zurück, ob eine Taste neu gedrückt
		//	wurde. Dabei wird jede Taste nur EINMAL gemeldet.
		//
		uint8_t GetKeyPress( uint8_t key_mask );


		//--------------------------------------------------------------
		//	Gibt die Information zurück, ob eine Taste lang genug
		//	gedrückt wurde, so dass die REPEAT-Funktion aktiviert wurde.
		//	Nach einer Anlaufverzögerung wird die jeweilige Taste in
		//	aufeinander folgenden Funktionsaufrufen immer wieder
		//	gemeldet, solange sie gedrückt bleibt.
		//
		uint8_t GetKeyRepeat( uint8_t key_mask );


		//--------------------------------------------------------------
		//	Gibt die Information zurück, ob eine Taste im Augenblick
		//	gedrückt ist.
		//
		uint8_t GetKeyState( uint8_t key_mask );


		//--------------------------------------------------------------
		//	Gibt die Information zurück, ob eine Taste kurz
		//	gedrückt wurde.
		//
		uint8_t GetKeyShort( uint8_t key_mask );


		//--------------------------------------------------------------
		//	Gibt die Information zurück, ob eine Taste lang
		//	gedrückt wurde.
		//
		uint8_t GetKeyLong( uint8_t key_mask );

		//--------------------------------------------------------------
		//	sets the low active mask to invert individual input bits
		//
		//	Parameter:
		//		low_active_mask	Specifies in a bit mask which inputs
		//						will work low active and need to
		//						be inverted
		//
		inline void SetLowActiveMask( uint8_t low_active_mask )
		{
			m_usLowActiveMask = low_active_mask;
		};

		//--------------------------------------------------------------
		//	sets the repeat mask to enable the repeat function for
		//	the inputs that are denoted in the bit field
		//
		//	Parameter:
		//		repeat_mask	Specifies in a bit mask for which keys the
		//					repeat function will be switched on
		//
		inline void SetRepeatMask( uint8_t repeat_mask )
		{
			m_usRepeatMask = repeat_mask;
		};

		//--------------------------------------------------------------
		//	sets the repeat start and repeat next delays
		//
		//	Parameter:
		//		repeat_start
		//		repeat_next
		//
		inline void SetRepeatDelays(	uint8_t repeat_start,
										uint8_t repeat_next		)
		{
			m_usRepeatStart	= repeat_start;
			m_usRepeatNext	= repeat_next;
		}
};

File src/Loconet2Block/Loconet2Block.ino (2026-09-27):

//##########################################################################
//#
//#	LocoNet2Block		copyright: Michael Pfeil
//#
//#	Dieses Programm ist für die Hardware Loconet2Block geschrieben.
//# Hier wird die Funktionalität des Streckenblocks abgebildet.
//#	Als Vorlage dienen die State-Modelle von Stefan Bormann.
//#
//#-------------------------------------------------------------------------
//#
//#	Needed resources:
//#		LocoNet Library		V 1.1.13
//#		SimpleOled Library	V 1.2.1
//#
//##########################################################################

#include "compile_options.h"

//----------------------------------------------------------------------
//	The main version is defined by PLATINE_VERSION (compile_options.h)
//
//#define VERSION_MAIN		PLATINE_VERSION

#define	VERSION_MINOR		36
#define VERSION_BUGFIX		1

#define VERSION_NUMBER		((PLATINE_VERSION * 1000) + (VERSION_MINOR * 10) + VERSION_BUGFIX)


//##########################################################################
//#
//#		Version History:
//#
//#-------------------------------------------------------------------------
//#
//#	Version:	x.36.01		from: 03.06.2026
//#
//#	Implementation:
//#		-	add config for track contacts as known
//#			changes in files
//#				my_loconet.cpp, my_loconet.h
//#
//#-------------------------------------------------------------------------
//#
//#	Version:	x.36.00		from: 30.05.2026
//#
//#	Implementation:
//#		-	add second track contact
//#			changes in files
//#				io_control.cpp, io_control.h
//#				data_pool.cpp, data_pool.h
//#				my_loconet.cpp, my_loconet.h
//#
//#-------------------------------------------------------------------------
//#
//#	Version:	x.35.01		from: 07.01.2026
//#
//#	Bug Fix:
//#		-	change version numbering from p.vv.bb to p.vv.b
//#			where	p	platine version
//#					vv	version minor
//#					b	verion bugfix
//#
//#-------------------------------------------------------------------------
//#
//#	Version:	x.35.00		from: 01.01.2026
//#
//#	Implementation:
//#		-	add the handling for a distant signal
//#			the state of the 'Einfahrt-Signal' will be send over the
//#			block line to the next station to control a distant signal
//#			on the other hand if a signal message will be received over
//#			the block line then a configured distant signal will be
//#			controlled.
//#			add a new file
//#				signal_aspect_codes.h
//#			changes in files
//#				data_pool.cpp, data_pool.h
//#				lncv_storage.cpp, lncv_storage.h
//#				my_loconet.cpp
//#				Loconet2Block.ino
//#
//#-------------------------------------------------------------------------
//#
//#	Version:	x.34.03		from: 23.10.2025
//#
//#	Bug Fix:
//#		-	wrong evaluation of LED on and block detect
//#			changes in file
//#				io_control.cpp
//#
//#-------------------------------------------------------------------------
//#
//#	Version:	x.34.02		from: 23.10.2025
//#
//#	Bug Fix:
//#		-	change control of LEDs from pin number to mask
//#
//#-------------------------------------------------------------------------
//#
//#	Version:	x.34.01		from: 20.10.2025
//#
//#	Bug Fix:
//#		-	correction of I/O configuration
//#			change in files:
//#				io_control.h, io_control.cpp
//#
//#-------------------------------------------------------------------------
//#
//#	Version:	x.34.00		from: 13.10.2025
//#
//#	Implementation:
//#		-	add new platine version 7
//#			change in files:
//#				LocoNet2Block.ino
//#				io_control.h, io_control.cpp
//#				entprellung.h, entprellung.cpp
//#
//#-------------------------------------------------------------------------
//#
//#	Version:	x.33.01		from: 02.08.2025
//#
//#	Bug Fix:
//#		-	send only one message if Hupe is not controlled by block
//#			changes in file:
//#				data_pool.cpp
//#
//#-------------------------------------------------------------------------
//#
//#	Version:	x.33.00		from: 02.08.2025
//#
//#	Implementation:
//#		-	add two LNCV addresses to differentiate between the sounds
//#			for Erlaubniswechsel, Vor- and Rueckblock
//#			changes in files:
//#				lncv_storage.h, lncv_storage.cpp
//#				data_pool.h, data_pool.cpp
//#				anfangsfeld.cpp, endfeld.cpp, erlaubnis.cpp
//#
//#-------------------------------------------------------------------------
//#
//#	Version:	x.32.02		from: 08.07.2025
//#
//#	Bug Fix:
//#		-	improvement of key box handling
//#			changes in files: anfangsfeld.cpp, erlaubnis.cpp
//#				switch off of key permission whenever no "Ausfahrt" possible
//#				instead of only when "KEY_BOX_DIRECT" is configured
//#			changes in file: data_pool.cpp
//#				switch on of key permission per FdL is only possible when
//#				bit OUT_MASK_SCHLUESSELENTNAHME_MOEGLICH is set and
//#				message KEY_RELEASED was received.
//#
//#-------------------------------------------------------------------------
//#
//#	Version:	x.32.01		from: 22.06.2025
//#
//#	Bug Fix:
//#		-	only sent "Erlaubnis-Abgabe" when reconnecting the blockcable
//#			if "Richtungsbetrieb" is configured
//#			change in function
//#				loop()
//#
//#-------------------------------------------------------------------------
//#
//#	Version:	x.32.00		from: 21.08.2024
//#
//#	Implementation:
//#		-	improvement of button handling
//#			change in function
//#				loop()
//#
//#-------------------------------------------------------------------------
//#
//#	Version:	x.31.04		from: 21.08.2024
//#
//#	Bug Fix:
//#		-	improvement of notify messages
//#			don't react on notifySwitchReport and notifySwitchState
//#			to avoid missinterpretation of requests.
//#
//#-------------------------------------------------------------------------
//#
//#	Version:	x.31.03		from: 28.04.2024
//#
//#	Bug Fix:
//#		-	DebuggingClass::PrintTrainNumber()
//#				parameters in function 'memcpy()' were swaped.
//#
//#-------------------------------------------------------------------------
//#
//#	Version:	x.31.02		from: 14.02.2024
//#
//#	Bug Fix:
//#		-	in ESTGWJ mode no Uebertragungsstoerung message was send
//#
//#-------------------------------------------------------------------------
//#
//#	Version:	x.31.01		from: 11.02.2024
//#
//#	Bug Fix:
//#		-	the indication that a "Rückblock" is now possible now
//#			shows up when the state is "geräumt" and the E-Sig is in Hp0.
//#
//#-------------------------------------------------------------------------
//#
//#	Version:	x.31.00		from: 12.11.2023
//#
//#	Implementation:
//#		-	switch to LocoNet Library V1.1.13
//#		-	switch to new OLED library => SimpleOled V1.2.1
//#
//#-------------------------------------------------------------------------
//#
//#	Version:	x.30.00		from: 10.08.2023
//#
//#	Implementation:
//#		-	add a check if a display is connected and if not don't send
//#			anything to the display
//#
//#-------------------------------------------------------------------------
//#
//#	Version:	x.29.00		from: 09.08.2023
//#
//#	Implementation:
//#		-	change handling of ESTGWJ mode
//#
//#-------------------------------------------------------------------------
//#
//#	Version:	x.28.06		from: 09.08.2023
//#
//#	Bug Fix:
//#		-	in ESTGWJ mode no accustic signal was send
//#			change in function
//#				Loop()
//#
//#-------------------------------------------------------------------------
//#
//#	Version:	x.28.05		from: 07.08.2023
//#
//#	Bug Fix:
//#		-	problem after change of module address fixed
//#
//#-------------------------------------------------------------------------
//#
//#	Version:	x.28.04		from: 04.08.2023
//#
//#	Bug Fix:
//#		-	in ESTGWJ mode no Hupe was activated
//#
//#-------------------------------------------------------------------------
//#
//#	Version:	x.28.03		from: 26.07.2023
//#
//#	Bug Fix:
//#		-	by mistake no acknowledge was send when receiving a programming
//#			start with broadcast as address.
//#
//#-------------------------------------------------------------------------
//#
//#	Version:	x.28.02		from: 21.07.2023
//#
//#	Bug Fix:
//#		-	in ESTGWJ mode no train messages were send
//#			change in function
//#				loop()
//#
//#-------------------------------------------------------------------------
//#
//#	Version:	x.28.01		vom: 18.07.2023
//#
//#	Bug Fix:
//#		-	do not go into prog mode when a programming start msg
//#			with broadcast address was detected
//#		-	wrong basis address for the port extender used for the
//#			old style station interface
//#
//#-------------------------------------------------------------------------
//#
//#	Version:	x.28.00		vom: 20.06.2023
//#
//#	Implementation:
//#		-	add functionality for the old style station interface
//#			change in function
//#				setup()
//#
//#-------------------------------------------------------------------------
//#
//#	Version:	x.27.01		vom: 04.06.2023
//#
//#	Bug Fix:
//#		-	do not go into prog mode when a discover msg was detected
//#
//#-------------------------------------------------------------------------
//#
//#	Version:	x.27.00		vom: 16.05.2023
//#
//#	Implementation:
//#		-	new definitions for train number field types
//#				TRAIN_NUMBER_FIELD_ALL
//#			this type is used to address all ZN fields with one message
//#
//#-------------------------------------------------------------------------
//#
//#	Version:	x.26.03		vom: 07.04.2023
//#
//#	Bug Fix:
//#		-	ignore the second switch message with output set to '0'
//#
//#-------------------------------------------------------------------------
//#
//#	Version:	x.26.02		vom: 09.02.2023
//#
//#	Bug Fix:
//#		-	wrong variable name when using the U8x8 library
//#		-	error when printing ZN numbers
//#
//#-------------------------------------------------------------------------
//#
//#	Version:	x.26.01		vom: 07.02.2023
//#
//#	Bug Fix:
//#		-	wrong messages were send
//#
//#-------------------------------------------------------------------------
//#
//#	Version:	x.26.00		vom: 03.02.2023
//#
//#	Implementation:
//#		-	new block message code for train number messages
//#			change in function
//#				HandleBlockMessage()
//#
//#-------------------------------------------------------------------------
//#
//#	Version:	x.25.01		vom: 01.02.2023
//#
//#	Bug Fix:
//#		-	wrong text output when receiving 'Rückblock' messages
//#
//#	Implementation:
//#		-	change train number field codes to new definitions
//#
//#-------------------------------------------------------------------------
//#
//#	Version:	x.25.00		vom: 31.01.2023
//#
//#	Implementation:
//#		-	add ESTWGJ mode
//#			in this mode no state machine is working
//#			Vorblock, Rückblock and Erlaubniswechsel will be send directly
//#			all checks and all other message sending are disabled
//#
//#-------------------------------------------------------------------------
//#
//#	Version:	x.24.09		vom: 23.01.2023
//#
//#	Implementation:
//#		-	new address for annunciator numbers
//#			now there are a local and a remote annunciator number
//#		-	new order of the train number LNCVs
//#
//#-------------------------------------------------------------------------
//#
//#	Version:	x.24.08		vom: 04.01.2023
//#
//#	Bug Fix:
//#		-	send 'Fahrt möglich' only a few times, not every 5 seconds
//#		-	don't react on Loconet messages when Block is OFF
//#
//#-------------------------------------------------------------------------
//#
//#	Version:	x.24.07		vom: 04.01.2023
//#
//#	Implementation:
//#		-	new order of display lines
//#		-	bitfield always visible
//#
//#-------------------------------------------------------------------------
//#
//#	Version:	x.24.06		vom: 04.01.2023
//#
//#	Implementation:
//#		-	new Block Off printout
//#
//#	Bug Fix:
//#		-	forget to read Block ON/OFF message address
//#		-	train numbers were not shown on the display, because
//#			the debugging function Loop() was not called from main program.
//#
//#-------------------------------------------------------------------------
//#
//#	Version:	x.24.05		vom: 15.12.2022
//#
//#	Bug Fix:
//#		-	train numbers were not shown on the display
//#
//#-------------------------------------------------------------------------
//#
//#	Version:	x.24.04		vom: 13.12.2022
//#
//#	Implementation:
//#		-	add train numbers on debug display
//#
//#-------------------------------------------------------------------------
//#
//#	Version:	x.24.03		vom: 09.12.2022
//#
//#	Implementation:
//#		-	send 'Erlaubnisabgabe' after re-connection of blockcable
//#
//#-------------------------------------------------------------------------
//#
//#	Version:	x.24.02		vom: 02.12.2022
//#
//#	Implementation:
//#		-	changes in Richtungsbetrieb
//#			reduce amount of loconet messages
//#			-	1s after RESET send Erlaubnis-Abgabe message
//#				over blockcable
//#			-	then every 2s send Erlaubnis-Abgabe message again until
//#				an acknowledge was received
//#
//#-------------------------------------------------------------------------
//#
//#	Version:	x.24.01		vom: 24.11.2022
//#
//#	Implementation:
//#		-	only print information when data has changed
//#
//#-------------------------------------------------------------------------
//#
//#	Version:	x.24.00		vom: 19.11.2022
//#
//#	Implementation:
//#		-	if EntryTimer is configured to '0' then directly go to
//#			state 'ENDFELD_STATE_GERAEUMT'
//#
//#-------------------------------------------------------------------------
//#
//#	Version:	x.23.02		vom: 19.11.2022
//#
//#	Bug Fix:
//#		-	avoid phantom messages during sending the out state
//#
//#-------------------------------------------------------------------------
//#
//#	Version:	x.23.01		vom: 16.11.2022
//#
//#	Bug Fix:
//#		-	status of "Block ON" and "Train Numbers ON" were not set
//#			correctly during 'Init()'
//#
//#-------------------------------------------------------------------------
//#
//#	Version:	x.23.00		vom: 16.11.2022
//#
//#	Implementation:
//#		-	reorganize LNCV configuration
//#
//#-------------------------------------------------------------------------
//#
//#	Version:	x.22.01		vom: 14.11.2022
//#
//#	Implementation:
//#		-	change loconet message handling
//#
//#-------------------------------------------------------------------------
//#
//#	Version:	x.22.00		vom: 01.11.2022
//#
//#	Implementation:
//#		-	add message to switch the box OFF / ON
//#			changes in function 'LoconetReceived()'
//#
//#-------------------------------------------------------------------------
//#
//#	Version:	x.21.00		vom: 02.10.2022
//#
//#	Implementation:
//#		-	add version number into LNCV #5
//#		-	add new config bit 'CONTACT_REMAINS_ACTIVE'
//#			if this bit is set in the endfield state model the transition
//#			from 'signal_gezogen' to 'belegt' is disabled.
//#		-	'my_loconet.cpp':
//#			store article number and module address in global variables
//#			to simple access and speed up LNCV read and write
//#		-	change function 'PrintStorageCheck()' to print
//#				LNCV #0		module address
//#				LNCV #1		article number
//#
//#	Bug Fix:
//#		-	only write to EEPROM if the new value is different
//#			than the old one
//#
//#-------------------------------------------------------------------------
//#
//#	Version:	x.20.00		vom: 09.09.2022
//#
//#	Implementation:
//#		-	the flag for train numbers moved to 'lncv_storage',
//#			because it will be stored permanent now.
//#
//#-------------------------------------------------------------------------
//#
//#	Version:	x.19.01		vom: 28.08.2022
//#
//#	Bugfix:
//#		-	the flag to send out the states for all OUT-Loconet-Device
//#			was not cleared after sending. This is corrected now.
//#
//#-------------------------------------------------------------------------
//#
//#	Version:	x.19.00		vom: 28.08.2022
//#
//#	Implementation:
//#		-	add a send out of all OUT-Loconet-Device states after
//#			power on or reset
//#		-	add address to send the state of all OUT-Loconet-Devices
//#
//#-------------------------------------------------------------------------
//#
//#	Version:	x.18.01		vom: 26.08.2022
//#
//#	Bugfix:
//#		-	support of 2 display libraries implemented therefor
//#			the compile switch 'USE_SIMPLE_DISPLAY_LIB' was added
//#			in 'compile_options.h'. If the switch is defined then the
//#			simple display lib is used.
//#
//#-------------------------------------------------------------------------
//#
//#	Version:	x.18.00		vom: 09.07.2022
//#
//#	Implementation:
//#		-	add reset functionality over loconet
//#
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
void loop()
{
	uint8_t		uiAction	= DO_NOTHING;


	//==================================================================
	//	Read Inputs
	//	-	Loconet messages
	//	-	Block messages
	//	-	Input signals
	//	all inputs will be stored in the 'data pool'
	//
	if( g_clMyLoconet.CheckForMessageAndStoreInDataPool() )
	{
		resetFunc();
	}

	if( CheckForBlockMessage() )
	{
		HandleBlockMessage();

		//----------------------------------------------------------
		//	!!	ATTENTION  !!
		//	don't forget to 'reset' the receive buffer after
		//	handling the message !
		//
		g_usReceived = 0;
	}


	//==================================================================
	//	Auswertung der Daten und logische Verknüpfungen abarbeiten.
	//	Die Ergebnisse landen wieder im 'data_pool'.
	//
	uiAction = g_clDataPool.InterpretData();

	switch( uiAction )
	{
		case DO_RESET:
			resetFunc();
			break;

		case DO_RECONNECTED:
			if( g_clLncvStorage.IsConfigSet( RICHTUNGSBETRIEB ) )
			{
				g_bSendErlaubnisabgabe = true;
			}
			break;

		case DO_NOTHING:
		default:
			break;
	}

	//--------------------------------------------------------------
	//	Wurde der Programmier-Modus beendet ?
	//
	if( g_clDataPool.IsProgMode() != g_bIsProgMode )
	{
		if( g_bIsProgMode )
		{
			resetFunc();
		}
		else
		{
			g_bIsProgMode = true;
		}
	}


	//==================================================================
	//	Prüfen, ob wiederkehrende Aktionen ausgeführt werden sollen.
	//	Z.B.:	im Richtungsbetrieb die Erlaubnis abgeben oder
	//			im BLOCK OFF Zustand die Ausfahrsignale freigeben.
	//
	if( millis() > g_ulMillisRepeat )
	{
		if( g_clLncvStorage.IsBlockOn() )
		{
			//----------------------------------------------------------
			//	2 Sek. nach einem Reset werden einmal alle Zuständer
			//	der OUT-Loconet-Devices gesendet.
			//
			if( g_bSendOutStates )
			{
				g_bSendOutStates = false;

				if( g_bIsEstwgjMode )
				{
					g_clMyLoconet.SendMessageWithOutAdr( OUT_IDX_VORBLOCKMELDER_RELAISBLOCK, 0 );
					g_clMyLoconet.SendMessageWithOutAdr( OUT_IDX_RUECKBLOCKMELDER_RELAISBLOCK, 1 );
				}
				else
				{
					g_clDataPool.SendOutState();
				}
			}

			//----------------------------------------------------------
			//	Im Richtungsbetrieb wird alle zwei Sekunden
			//	die Erlaubnis abgegeben, bis ein Ack gelesen wurde.
			//
			if( g_bSendErlaubnisabgabe )
			{
				SendBlockMessage( DP_BLOCK_MESSAGE_ERLAUBNIS_ABGABE );
			}
		}
		else
		{
			//----------------------------------------------------------
			//	Im BLOCK OFF Zustand die Ausfahrsignale freigeben und
			//	Ausfahrten ermöglichen und ein paar mal alle Melder
			//	und Anzeigen ausschalten.
			//
			if( 0 < g_iOffCounter )
			{
				g_iOffCounter--;
				
				g_clDataPool.ClearOutStatePrevious(		OUT_MASK_FAHRT_MOEGLICH
													|	OUT_MASK_NICHT_ZWANGSHALT
													|	OUT_MASK_SCHLUESSELENTNAHME_MOEGLICH );

				g_clDataPool.SetOutStatePrevious(	OUT_MASK_AUSFAHRSPERRMELDER_TF71
												|	OUT_MASK_BLOCKMELDER_TF71
												|	OUT_MASK_WIEDERHOLSPERRMELDER_RELAISBLOCK
												|	OUT_MASK_VORBLOCKMELDER_RELAISBLOCK
												|	OUT_MASK_RUECKBLOCKMELDER_RELAISBLOCK
												|	OUT_MASK_MELDER_ANSCHALTER
												|	OUT_MASK_MELDER_ERSTE_ACHSE
												|	OUT_MASK_MELDER_GERAEUMT
												|	OUT_MASK_MELDER_GERAEUMT_BLINKEN
												|	OUT_MASK_UEBERTRAGUNGSSTOERUNG
												|	OUT_MASK_MELDER_ERLAUBNIS_ERHALTEN
												|	OUT_MASK_MELDER_ERLAUBNIS_ABGEGEBEN );
			}
		}

		//--------------------------------------------------------------
		//	Timer neu starten
		//	Im "Block Off" Zustand werden Nachrichten alle 5 Sekunden,
		//	im "Block ON" Zustand alle 2 Sekunden gesendet.
		//
		if( 0 == g_iOffCounter )
		{
			g_ulMillisRepeat = millis() + cg_ulInterval_5_s;
		}
		else
		{
			g_ulMillisRepeat = millis() + cg_ulInterval_2_s;
		}
	}

	if( 0 < g_ulMillisErlaubnisabgabe )
	{
		if( millis() > g_ulMillisErlaubnisabgabe )
		{
			g_clDataPool.SetInState( IN_MASK_BEDIENUNG_ERLAUBNISABGABE );

			g_ulMillisErlaubnisabgabe = 0;
		}
	}


	//==================================================================
	//	Die State-Maschinen abarbeiten
	//
	if( !g_bIsEstwgjMode )
	{
		erlaubnis_state_t	erlaubnisState	= g_clErlaubnis.CheckState();

		if( ERLAUBNIS_STATE_ERHALTEN == erlaubnisState )
		{
			g_clAnfangsfeld.CheckState();
		}

		if( ERLAUBNIS_STATE_ABGEGEBEN == erlaubnisState )
		{
			g_clEndfeld.CheckState();
		}
	}

	//==================================================================
	//	Auswerten, ob Melder oder sonstiges über das Loconet
	//	gesendet werden sollen und/oder ob Blocknachrichten
	//	über das Kabel gesendet werden sollen.
	//
	if(		g_clLncvStorage.IsTrainNumbersOn()
		&&	g_clLncvStorage.IsConfigSet( TRAIN_NUMBERS ) )
	{
		if( g_clDataPool.IsNewMsgStation2Block() )
		{
			uint8_t	*pBuffer = g_clDataPool.GetStation2Block();

#if PLATINE_VERSION == 7
			Serial1.write( pBuffer, g_clDataPool.GetTrainNoStation2BlockLen() );
#else
			Serial.write( pBuffer, g_clDataPool.GetTrainNoStation2BlockLen() );
#endif

#ifdef DEBUGGING_PRINTOUT
			g_clDebugging.PrintSendBlockMsg( *(pBuffer + 1) );
#endif

			*pBuffer = 0x00;
		}
	}

	CheckForBlockOutMessages();

	g_clDataPool.CheckForOutMessages();

#ifdef DEBUGGING_PRINTOUT
	g_clDebugging.Loop();
#endif

	//-------------------------------------------------------------
	//	ensure that there is no 'old' keypress in stock
	//
	g_clDataPool.ClearInState(		IN_MASK_BEDIENUNG_RUECKBLOCK
								|	IN_MASK_BEDIENUNG_HILFSVORBLOCK
								|	IN_MASK_BEDIENUNG_ERLAUBNISABGABE
								|	IN_MASK_BEDIENUNG_ANSCHALTER_EIN
								|	IN_MASK_BEDIENUNG_ANSCHALTER_AUS );
}

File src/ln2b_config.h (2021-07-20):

//
// Block messages
//
#define VORBLOCK            42
#define RUECKBLOCK          43
#define ERLAUBNISABGABE     44
#define ERLAUBNISANFRAGE    45
#define ACHSSENSOR          46
#define ESIG                47
#define CONFIG              48
#define AZGT                49
#define BLOCK_ZUSTAND       50
#define BLOCK_BEFEHL        51
#define ANSTOSSMELDUNG      52
#define GSKZ                53
#define VORBLOCK_ACK        142
#define RUECKBLOCK_ACK      143
#define ERLAUBNISABGABE_ACK 144
#define ERLAUBNISANFRAGE_ACK  145
#define END                 192    // indicates end of packet
#define ESC                 219    // indicates byte stuffing
#define ESC_END             220    // ESC ESC_END means END data byte
#define ESC_ESC             221    // ESC ESC_ESC means ESC data byte

#define RX_INPUT_PIN    0 
#define RX2_INPUT_PIN   5 
#define LN_TX_PIN       7 

#define KEINER 0
#define ERHALTEN 1
#define ABGEGEBEN 2
#define HOLEN 3

#define BLOCK_FREE  1
#define BLOCK_OCC 2

#define On true
#define Off false

/*
 * endfeldState values
 */
#define frei_boot 0
#define frei 1
#define belegt 2
#define signal_gezogen 3
#define anschalter_aktiv 4 
#define erste_achse 5
#define geraeumt 6 

/*
 * anfangsfeldState values
 */
//#define frei 1
//#define belegt 2
#define fahrt 3
#define fluegel_kupplung 4
#define einfahrsignal 5
#define fahrt_pre 6

/*
 * eventnumbers
 */
#define AusfahrtSignalFahrt 11
#define AusfahrtSignalHalt 12
#define GleiskontaktBefahren 13
#define ErlaubnisAbgabeTasteBedient 14 //EaT_BlGT
#define EinfahrtSignalFahrt 15
#define EinfahrtSignalHalt 16
#define RbT_BlGT_Bedient 17 //RbT-BlGT
//#define GleiskontaktExitBefahren 18
#define VbHT_BlGTBedient 19 //VbHT_BlGT
#define AsT_RbT_Bedient 20 //AsT_RbT
#define AsLT_RbT_Bedient 21 //AsLT_RbT

/*
 * led ports
 */
#define LED_BLOCK_POWER_BLUE       A0
#define LED_YELLOW_BLOCKING_HERE   A1
#define LED_RED_BLOCK_OCCUPIED     A2
#define LED_GREEN_BLOCK_ACTIVE     A3

/*
 * LNCV
 */

#define VERSION 5
#define ARTNR 1532 //enter 15320 in article ID on Intellibox
#define LNCV_COUNT 24

#define LNUStoer 2              //Sensor, output to panel High=Stoer, Low = OK
#define LNASpM 4                //switch, Ausfahrsperre blauer klaus Tf71, output to panel
#define LNBlockMelder 5         //sensor, output to panel 
#define LNWSpM 6                //switch, Wiederholsperre blauer klaus RB, output to panel
#define LNVorblockMelder 7      //sensor, ouput
#define LNRueckBlockMelder 8    //sensor, ouput
#define LNAnschaltMelder  9     //sensor, output
#define LNRaeumungsMelder 11    //sensor, output
#define LNWecker 12             //sensor, output to panel
#define LNTastensperre_EaT 13   //to lock EaT button on SMF Panel (LNCV 38 of the SMF EaT module)
#define LNErlaubnisAbgabeRichting 14 //Erlaubnismelder is coupled to EaT direction state/arrow on panel (LNCV 87 of EaT module)

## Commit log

2021-09-15 lncv calculator added
    [lncv-calculator.xlsm]
2021-09-15 added value explanation
    [lncv-calculator.xlsm]
2021-10-10 Felderblock prototype hardware
    Felderblock prototype hardware
    [Felderblock mini.brd, Felderblock mini.sch]
2021-10-28 added Loconet delay
    To prevent flooding Loconet a delay can be set between individual messages the board sends out. You can configure the time using LNCV #9.
    The default time is 10 ms.
    The software will take care that the minimum delay time is not less than 5 ms.
    [lncv_storage.h]
2021-11-12 remove macro
    [lncv-calculator.xlsm]
2021-11-12 tab names
    [lncv-calculator.xlsm]
2021-11-12 Swap OLED Orientation implemented
    Add a configuration bit to control the orientation of the OLED display. If bit is set then the display will be turned by 180 degree.
    [debugging.cpp, lncv_storage.h]
2021-11-12 Rename of .ino file
    Rename the .ino file so that the project can be compiled with Arduino IDE.
2021-11-13 flip display in calculator
    [lncv-calculator.xlsm]
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2021-11-14 1ste Achse counter re-trigger implemented
    Im State ENDFELD_STATE_ERSTE_ACHSE wird bei jeder Gleiskontakt-Belegt-Nachricht der Timer für GERAEUMT neu gestartet.
2021-11-15 blocktypes added
    [lncv-calculator.xlsm]
2021-11-15 Felderblock implemented
    Ein neues Konfigurationsbit "FELDERBLOCK" eingebaut.
    Wenn das Bit gesetzt ist, wird im Anfangsfeld im Zustand "ANFANGSFELD_STATE_FLUEGEL_KUPPLUNG" kein automatischer Vorblock mehr gesendet. Stattdessen wird darauf gewartet, dass der Gleiskontakt wieder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
2021-11-24 First version of split boards
    [Felderblock_Grundplatine.brd, Felderblock_Grundplatine.sch, Felderblock_Hebelplatine.brd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]
2021-12-03 MI+AsT integrated
    LED nach I2C, MI links und rechts, AsT und AsM integriert. Board rerouted
    [Felderblock_Grundplatine.brd, Felderblock_Grundplatine.sch]
2021-12-03 Update Felderblock_Grundplatine.brd
    Mirror MI
    [Felderblock_Grundplatine.brd]
2021-12-03 Changed pin order on MCP
    MCP moved to other side, changed pin order
    [Felderblock_Grundplatine.brd, Felderblock_Grundplatine.sch]
2021-12-04 housekeeping
    some reroutes, text optimized
    [Felderblock_Grundplatine.brd, Felderblock_Grundplatine.sch]
2021-12-04 position pcb into housing
    restructure parts for housing, made pcb smaller to fit housing, positioned LED and buttons to fit
    [Felderblock_Grundplatine.brd]
2021-12-04 name
    Name label added
    [Felderblock_Grundplatine.brd]
2021-12-04 CW and CCW split
    [Felderblock_Grundplatine.brd, Felderblock_Grundplatine.sch]
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2021-12-05 tweaked layout
    [Felderblock_Hebelplatine.brd]
2021-12-05 moved I2C connectors
    [Felderblock_Hebelplatine.brd]
2021-12-05 Add timer configuration
    Add timer configuration, reorganise configuration bits and correct the functionality of the timers.
    [Loconet2Block.ino, lncv_storage.h]
2021-12-05 Update lncv-calculator.xlsm
    updated excel sheet
    [lncv-calculator.xlsm]
2021-12-06 changed I2C connectors
    [Felderblock_Grundplatine.brd, Felderblock_Grundplatine.sch, Felderblock_Hebelplatine.brd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]
2021-12-06 I2c moved
    So as not to interfere with other cables. other cables go up, i2c goes down to daughterboard
    [Felderblock_Grundplatine.brd, Felderblock_Grundplatine.sch]
2021-12-13 changed holes for switches to oval ones
    [Felderblock_Hebelplatine.brd, Felderblock_Hebelplatine.sch]
2021-12-19 some tuning
    [Felderblock mini.brd, Felderblock mini.sch, Felderblock_Grundplatine.brd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]
2021-12-20 last check
    [Felderblock_Hebelplatine.brd, Felderblock_Hebelplatine.sch]
2021-12-21 last update for mfg
    [Felderblock_Grundplatine.brd, Felderblock_Grundplatine.sch, Felderblock_Hebelplatine.brd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]
2022-01-03 LED 10mm updated
    changes:
    - footprint 10mm LED
    - INT not connected to GND (=output)
    [Felderblock_Grundplatine.brd, Felderblock_Grundplatine.sch]
2022-01-04 Update Felderblock_Grundplatine.brd
    dimension layer error fixed. triggered by pcb manufacuring
    [Felderblock_Grundplatine.brd]
2022-01-05 added v6 hardware
    V6 hardware with sideways DIN plug and config dipsettings
    [ln2block_6s.brd, ln2block_6s.sch]
2022-01-05 Implementation Block On / Off
    Block ON / OFF is now working. A short press on the button will toggle between ON and OFF. This is also shown on the display.
    Richtungsbetrieb is now working fine.
    Green LED will reflect the status of "Block belegt"
    File "compile_options.h" will be ignored by GitHub.
    [Loconet2Block.ino, debugging.cpp]
2022-01-05 HotFix Richtungsbetrieb and Anrueckmelder
    Correction for Richtungsbetrieb and Anrueckmelder
    [Loconet2Block.ino]
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2022-01-15 Bug Fix
    Missing includes inserted in data_pool.cpp
    When receiving an LncvWrite message the debug text shows now the correct word 'write'.
2022-01-16 Bug Fix: button evaluation
    The 'remembering' of button messages led again and again to Problems such as: 'automatic' triggering of a state change.
    This problem is now fixed.
    [Loconet2Block.ino]
2022-02-18 corrected errors
    LEDs connections corrected, address for MCP23008 corrected, reset for MCP23008 corrected
    [Felderblock_Grundplatine.brd, Felderblock_Grundplatine.sch]
2022-02-26 change version numbering
    the version number is composed of main, minor and develop/bug fix part
    for example: 4.14.01
    the main part is equal to the board version
    the minor part reflects a new feature
    the develop/bug fix part is just a number that is counted up.
    [debugging.cpp]
2022-02-26 add annunciator field for train numbers
    now there are 3 train numbers that can be forwarded over the block cable
    Offer, annunciator and track field numbers.
    to transport the LN display message over the block cable the broadcast type of message is used
    the payload of the broadcast is the LN message for setting a train number field.
    so byte 2 of the broadcast is 0xE5 which in turn is the opc for the LN display message
    broadcast: http://fremo-block.sourceforge.net/BlockInterface/MessageBroadcast.de.html
    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
2022-03-05 moved components to backside
    - Components of main panel moved to backside
    - corrected connections for MCP on Hebelplatine
    - added address jumpers on Hebelplatine
    [Felderblock_Grundplatine.brd, Felderblock_Hebelplatine.brd, Felderblock_Hebelplatine.sch]
2022-03-05 add enabling of train number message handling over Loconet
    add a flag 'TrainNoEnabled' in class data_pool and functions to set and read the flag.
    add address in Loconet class to switch the enable flag.
    now the configuration bit for TrainNoHandling and the new flag must be set
    to enable the TrainNo message handling.
2022-03-24 clear "Erlaubnisabgabe" message marker in State "erhalten" when set.
    if the box is in state "erhalten" more "Erlaubnisabgabe" messages can
    by received. These messages were remembered by a marker.
    The problem:
    If the box itself sends "Erlaubnisabgabe" to the other box, it sees
    the before remembered message an changes the state back to "erhalten".
    The result now is the both boxes are in the state "erhalten".
    Solution:
    Clear the marker for the "Erlaubnisabgabe" message when it is set and
    the box is in state "erhalten".
    [Loconet2Block.ino]
2022-03-31 bugfixes in class MyLoconetClass
    correction of parameter usage for switching train number messages on / off
    - function MyLoconetClass::LoconetReceived()
    avoid evaluation of per loop-back received train number messages
    - new member variable 'm_bIgnoreMsg' in MyLoconetClass
    - function MyLoconetClass::Init()
    - function MyLoconetClass::SendBlock2Station()
    - function MyLoconetClass::CheckForMessageAndStoreInDataPool()
    [Loconet2Block.ino]
2022-03-31 change the handling of receiving block messages
    Long messages like train number messages (and some times short messages, too)
    were not read in correctly.
    put the decoding of the SLIP message in a state machine and
    only read bytes from the serial interface when they are available.
    - new function HandleBlockMessage()
    - new function CheckForBlockMessage()
    - changed function loop()
    - deleted function RecvSlipPacket()
    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
    [Loconet2Block.ino]
2022-07-09 add reset over loconet
    [Loconet2Block.ino, lncv_storage.h]
2022-08-21 Changed to PCA9685
    - Changed LED-driver to PCA9685
    - Now two LED per field
    - Use LN-circuit with comparator
    [Felderblock_Grundplatine.brd, Felderblock_Grundplatine.sch]
2022-08-22 Rearranged order of LED and switches
    [Felderblock_Grundplatine.brd, Felderblock_Grundplatine.sch]
2022-08-24 Changed footprint for voltage regulator to TO220
    [Felderblock_Grundplatine.brd, Felderblock_Grundplatine.sch]
2022-08-26 add support of 2 display libraries new compile switch 'USE_SIMPLE_DISPLAY_LIB' added in 'compile_options.h' to control wich library to use. If the switch is defined then the simple display library wi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
2022-09-08 add a send out of all OUT-Loconet-Devices after Power On or Reset This sending of all states can also be triggered by a loconet message
    [Loconet2Block.ino, lncv_storage.h]
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2022-10-08 Extended to six fields
    Extended to six fields per PCB
    [Felderblock_Grundplatine.brd, Felderblock_Grundplatine.sch, Felderblock_Hebelplatine.brd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]
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2022-11-16 Bug Fix: state of 'Block ON' and 'Train Numbers ON' were not set correct during start up
    [Loconet2Block.ino]
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2022-11-19 Bug Fix: avoid phantom messages during sending the out state
    [Loconet2Block.ino]
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2022-11-24 Update lncv-calculator.xlsm
    update to last version for lncv storage
    [lncv-calculator.xlsm]
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2022-12-15 Vx.24.05: Bug Fix: train number were not shown on the display
    [Loconet2Block.ino, debugging.cpp]
2023-01-04 Vx.24.08: correct display and block off handling
    [Loconet2Block.ino]
2023-02-02 Vx.25.01: Bug Fix: show correct text info on the display now
    [Loconet2Block.ino, lncv_storage.h]
2023-02-07 Vx.26.01: Bug Fix: sometimes wrong text messages were shown
    [Loconet2Block.ino]
2023-03-06 Vx.26.02 Bug Fix: when using U8x8 lib there were wrong text outputs
    [Loconet2Block.ino, debugging.cpp]
2023-05-16 Vx.26.03: Bug Fix: ignore the second switch message with output set to '0'
    [Loconet2Block.ino]
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2023-06-04 Vx.27.01: Bug Fix: do not go into prog mode when a discover msg was detected
    [Loconet2Block.ino]
2023-07-26 Bug Fix: Vx.28.03: during ESTGWJ mode no ZN were send
    [Loconet2Block.ino, io_control.cpp]
2023-08-04 Vx.28.04: Bug Fix: no accustic signal was given in ESTGWJ mode
    [Loconet2Block.ino]
2023-08-07 Vx.28.05: Bug Fix: problem after change of module address fixed
    [Loconet2Block.ino]
2023-08-09 Vx.29.00: change handling of ESTWGJ mode: reset, signal
    [Loconet2Block.ino, debugging.cpp]
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2024-02-11 Vx.31.01: Bug Fix: correction of handling the 'rueckblock' indicator
    [Loconet2Block.ino]
2024-02-14 Vx.31.02: Bug Fix: in ESTGWJ mode no Uebertragungsstoerung msg was send
    [Loconet2Block.ino]
2024-04-28 Vx.31.02: Bug Fix: DebuggingClass::PrintTrainNumber(): parameters in function 'memcpy()' were swaped.
    [Loconet2Block.ino, debugging.cpp]
2024-08-21 Vx.31.04: Bug Fix: improvement of notify messages to avoid missinterpretation
    [Loconet2Block.ino]
2024-08-21 Vx.32.00: improvement of button handling, reset moved to main loop
    [Loconet2Block.ino]
2025-07-08 Vx.32.01: Bug Fix: improvement of key box handling
    [Loconet2Block.ino]
2025-07-08 Vx.32.01: Bug Fix: only sent 'Erlaubnisabgabe' when reconnecting in 'Richtungsbetrieb'
    [Loconet2Block.ino]
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2025-08-05 Vx.33.01: Bug Fix: send only one message if 'Hupe' is not controlled by block
    [Loconet2Block.ino]
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2026-01-01 bug fix: handling of LEDs and other I/Os
    [io_control.cpp]
2026-01-01 add on: wrong evaluation of distant signal aspect
    [Loconet2Block.ino]
2026-01-07 Vx.35.1: Bug Fix: change version number to readable number again
    [Loconet2Block.ino]
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2026-09-19 Bug Fix Vx.36.1: add missing config for second track contact
    [Loconet2Block.ino, debugging.cpp, io_control.cpp]

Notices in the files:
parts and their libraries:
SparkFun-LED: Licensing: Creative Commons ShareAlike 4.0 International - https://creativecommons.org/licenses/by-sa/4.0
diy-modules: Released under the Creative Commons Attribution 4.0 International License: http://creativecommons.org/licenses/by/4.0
